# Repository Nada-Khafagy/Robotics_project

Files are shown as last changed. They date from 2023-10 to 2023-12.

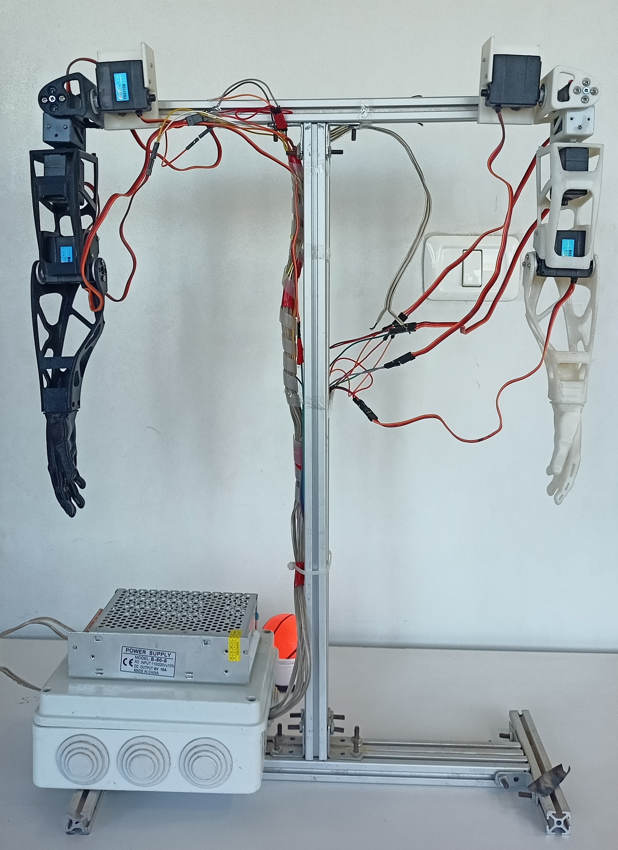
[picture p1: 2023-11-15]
right_arm/pics/wires_and _circuitry.jpg

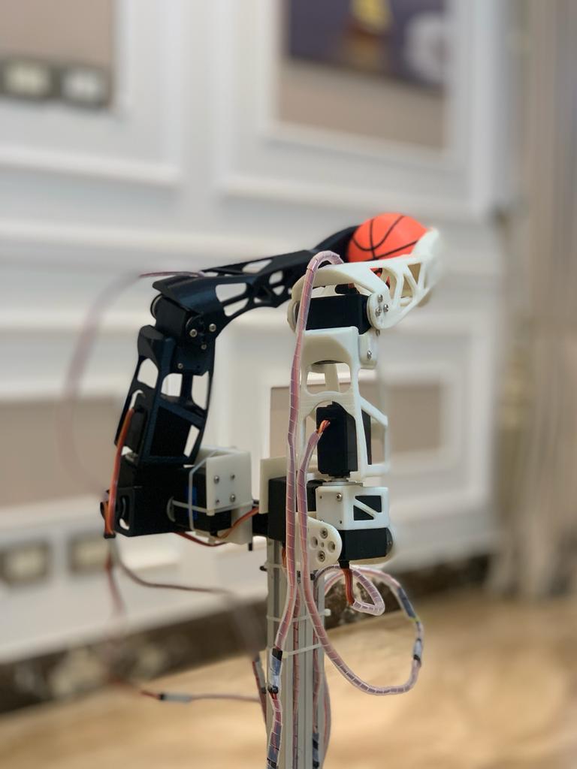
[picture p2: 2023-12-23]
RightLeftArms/fig/robot throwing the ball.jpg

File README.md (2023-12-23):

# Robotics_project

## Project Description

we will implement a robot that plays basketball :D 

# Basketball Project Team - slamDunk team
This is the official team page for the Basketball whole team. Meet our dedicated team members:

## Right Arm 
| Name | ID | GUC-mail | personal E-mail |
|---|---|---|---|
| Dina Mohamed | 49-18602 | dina.mohamed |dina67724@gmail.com |
| Marwa Lotfy | 49-18054 | marwa.hassan |lotfymarwa410@gmail.com  |
| Nada Tamer | 49-13614 | nada.abdelhay |nadatameer@outlook.com |
| Ahmed Mohamed Sleem |49-18230| ahmed.sleem |ahmedsleem.mail@gmail.com|
| Karim Emad Adam |49-17245 |karim.adam | |

## Left Arm 
| Name | ID | GUC-mail | personal E-mail |
|---|---|---|---|
| Shehab Ibrahim Mahmoud| 49-7639| shehab.abdallah | |
| Abdelfattah Gaber | 49-19487 | | |
| Ahmed Abdelhameed | 52-24471 | ahmed.elessawy | |
| Kareem Hindi | 49-3964  | Kareem.hindi |kareem.hindi12@gmail.com |
| Abdallah Amr | 49-10671 | | |

## To-Do List (Right hand)
- DONE :D

## To-Do List (Left hand)

## Project Timeline

- ~~registration --> 3/10~~
- ~~Milestone 1 --> 11/10~~
- ~~Milestone 2 --> 25/10~~
- ~~Milestone 3 --> 15/11~~
- ~~Milestone 4 --> 29/11~~
- ~~Milestone 5 --> 21/12~~
- DONE!!!!!!!!!!!!

## Video of working hardware
Robotic arm throwing a basket ball

## Contact Information
If you need to get in touch with our team, please feel free to reach out to us via the uni emails listed above by adding @student.guc.edu.eg or using personal mail.

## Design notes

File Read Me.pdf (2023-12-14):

To simulate the right arm only:

Open Matlab and simulink for the right arm >> Run humanoid_arm_DataFile >> Run HumanoidArmSyatem Simulink file

To simulate the both arms only:

Open Right and Left Simulink model >> Run Upper_Humanoid_DataFile >> Run Upper_Humanoid Simulink file

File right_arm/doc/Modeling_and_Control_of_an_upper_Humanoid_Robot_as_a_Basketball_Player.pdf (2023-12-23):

## Modeling and Control of an upper Humanoid Robot as a Basketball Player

Dina Mohamed∗

, Marwa Lotfy∗
,
Nada Tamer∗

, Ahmed Mohamed Sleem∗

and Karim Emad Adam∗
∗German University in Cairo (GUC), Egypt Emails: dina.mohamed@student.guc.edu.eg, marwa.hassan@student.guc.edu.eg, nada.abdelhay@student.guc.edu.eg, ahmed.sleem@student.guc.edu.eg, karim.adam@student.guc.edu.eg

Abstract—This project aims to design a system that can pick up and shoot a basketball with two robotic arms. It also focuses on creating interactive experiences for elderly individuals and children by engaging in playful activities with a softball. The project combines robotics, control systems, and entertainment to enhance well-being, social interaction, and physical activity for different age groups. Success will be measured by the system’s ability to accurately pick up and shoot the basketball.

Keywords-Robotics, Basketball, Control Systems.

I. INTRODUCTION

The integration of robotics and sports has marked a groundbreaking advancement in the field of technology, offering us the opportunity to explore new dimensions of human-machine interaction. In this context, our research delves into the fascinating realm of humanoid robotics, aiming to develop a Poppy humanoid arm system capable of playing basketball. This innovative project merges the intricacies of mechanical design, control, and robotics, presenting a significant step forward in the pursuit of enhancing both robotic capabilities and human-robot cooperation in dynamic and demanding environments.
The primary objective of this paper is to detail the design, modeling, and control strategies employed in the creation of a Poppy upper humanoid arm specifically optimized for playing basketball. The project seeks to bridge the gap between theoretical robotic design and real-world application in sports, with the ultimate goal of demonstrating how advanced robotics can be integrated into recreational activities, education, or even therapy for individuals with physical disabilities.
In section II, the robot’s hardware design and implementation is going to be presented.In section III techniques for forward kinematics are used, and techniques for Inverse kinematics are used in section IV. The section V presents the simulation results.

II. HARDWARE DESIGN AND IMPLEMENTATION

In order to build the hardware of the system, certain components are required as well, in addition, the connections circuit between the different components is shown.

A. Hardware Components
The poppy upper humanoid open source is used and 3D printed for hardware testing. For the motors, three double axes motors holding 10 kg.cm torque max and one motor holding 15 kg.cm for the shoulder to hold the whole system are used. ESP32 Microcontroller is used to control the four motors.

Table I: Hardware Components Table

Name of component | Location of purchasing | No. of items | Price
3D printed arm | Make It Real | 1 | 500
Servo motor 10kg.cm | Future electronics | 3 | 550
Servo motor 15kg.cm | Future electronics | 1 | 750
ESP32 | Ram electronics | 1 | 320
Power Supply | Ram electronics | 1 | 650
Wires, Jumpers | Future electronics | Some | 50
3d printed arm | Make It Real | 1 | 320
Aluminum Extrusion | CNC Egypt | 2 m | 160
L shape corner | CNC Egypt | 10 | 200
3d connecting part | Abdelhameed 3D printing | 1 | 50
Total | | | 3640
B. Circuit Diagram
As shown in Figure 1, the circuit consists of 4 motors, each having three connections, the voltage, the ground, and the signal which is the output of the micro controller. A breadboard is used to connect the wires at common nodes.

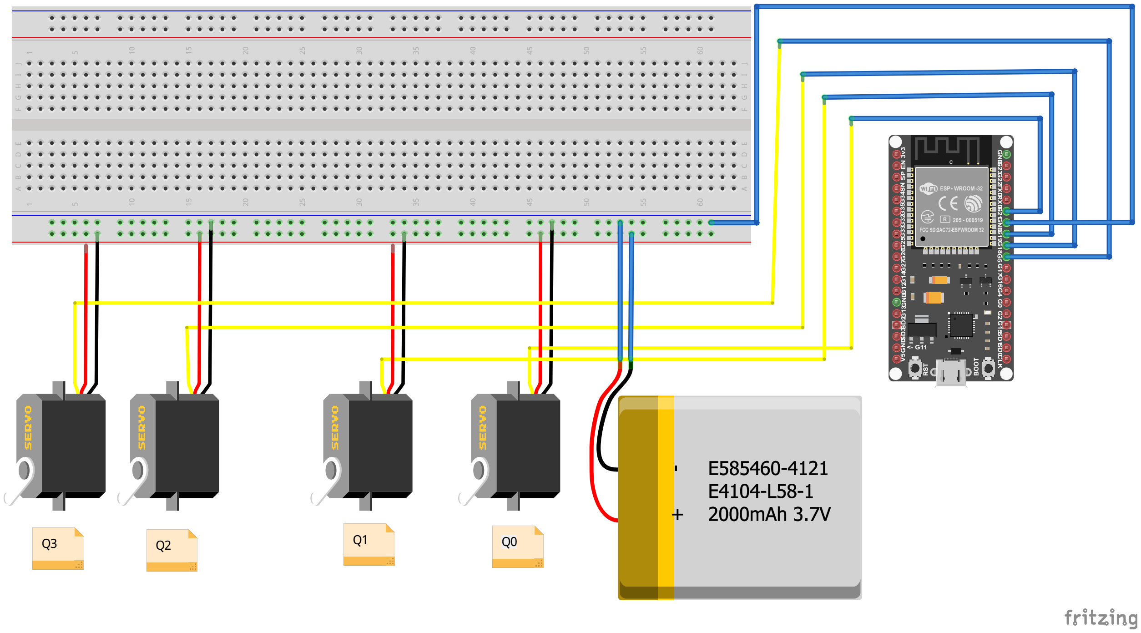
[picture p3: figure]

Figure 1: Circuit Diagram

III. FORWARD KINEMATICS

A. Denavit-Hartenberg (DH) convention

Forward kinematics using the Denavit-Hartenberg (DH) convention presented in [1] can be broken down into four key steps. First, assign DH axes to each joint of the robotic arm, ensuring they follow the right-hand rule as seen in Fig. 2. Second, fill out the DH parameters table, which includes values for the link lengths, joint angles, link twists, and offset distances, seen in II. This table is vital for the DH transformation process. Third, using these DH parameters, calculate the DH transformation matrices for each joint. These matrices represent the transformation between consecutive joints and are the building blocks for the final step. Lastly, obtain the end effector’s transformation matrix by multiplying the individual DH transformation matrices in a cascading manner. This final matrix describes the position and orientation of the robot’s end effector in the reference frame of the base, providing valuable information for controlling and planning the robot’s motion.

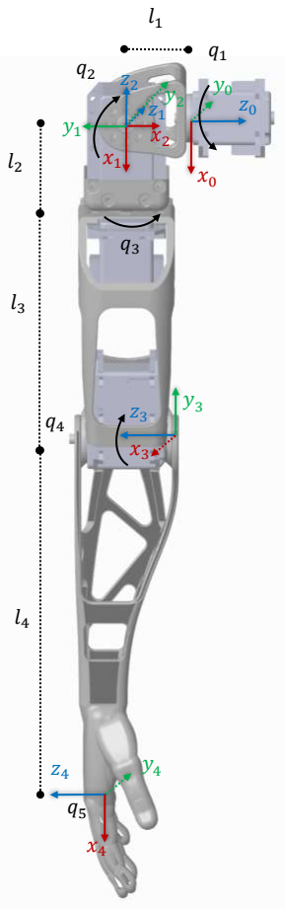
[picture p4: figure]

Figure 2: DH Frames.

joint(i) | θi | di | ai | αi
1 | q1 | −L1 | 0 | − π 2
2 | q2 − π 2 | 0 | 0 | π 2
3 | q3 − π 2 | −(L2 + L3) | 0 | π 2
4 | q4 − π 2 | 0 | L4 | 0

Table II: DH - Parameters table.

The distances between each joint is evaluated using a transform sensor and have the following values:

L1 | 0.02888114877491
L2 | 0.026599975
L3 | 0.122400025
L4 | 0.15

Table III: Lengths table.

IV. INVERSE KINEMATICS
Inverse kinematics refers to the process of determining the joint configurations of a robot’s manipulator that will result in a desired end-effector position and orientation. It involves finding the joint angles or joint displacements needed to achieve a specific pose (position and orientation) of the robot’s end-effector.
Let q represent the vector of joint variables, and p represent the desired end-effector position and orientation. The relationship between joint variables and end-effector pose is typically given by a kinematic function F(q):

F(q) = p

The goal of inverse kinematics is to solve for q given p. This is often a nonlinear problem due to the complex nature of robot kinematics.

A. Jacobian Matrix
The Jacobian matrix, denoted as J, relates the joint velocities q˙ to the end-effector linear and angular velocities v:

v = J(q) · q˙

Here, J(q) is the Jacobian matrix.

B. Newton-Raphson Method for Inverse Kinematics
The Newton-Raphson method is an iterative numerical technique used to find successively better approximations of the root of a real-valued function. In the context of inverse kinematics, it is applied to iteratively refine the joint variable estimates until the desired end-effector pose is achieved. The Newton-Raphson iteration for overactuated systems using the pseudo Jacobian can be expressed as:

qn+1 = qn + J

+(pdesired − F(qn))

Here,

- qn+1 is the updated estimate of joint variables.
- qn is the current estimate of joint variables.
- J

+ is the pseudo Jacobian matrix.
- pdesired is the desired end-effector pose.
- F(qn) is the current value of the kinematic function.

PSEUDO JACOBIAN FOR OVERACTUATED SYSTEM

In overactuated systems where we control more joints than the number of degrees of freedom of the end-effector (e.g., controlling x, y, z with 4 joints), the pseudo Jacobian J

+
can be used. For a 3-by-4 Jacobian J, the pseudo Jacobian is given by:

J

+ = J

T

(JJT
)

−1

This pseudo Jacobian allows the computation of joint velocities even in cases where the system is overactuated. The Newton-Raphson iteration for solving the inverse kinematics problem can then be modified with the pseudo Jacobian.
5
V. SIMULATIONS
A. Block diagram

The robot arm is exported from Solidworks, and then imported to Simscape and tested with different inputs, constants, sine waves, signal editor, and lastly, a slider. the following figures show the block diagram with the implemented forward and inverse Kinematics.

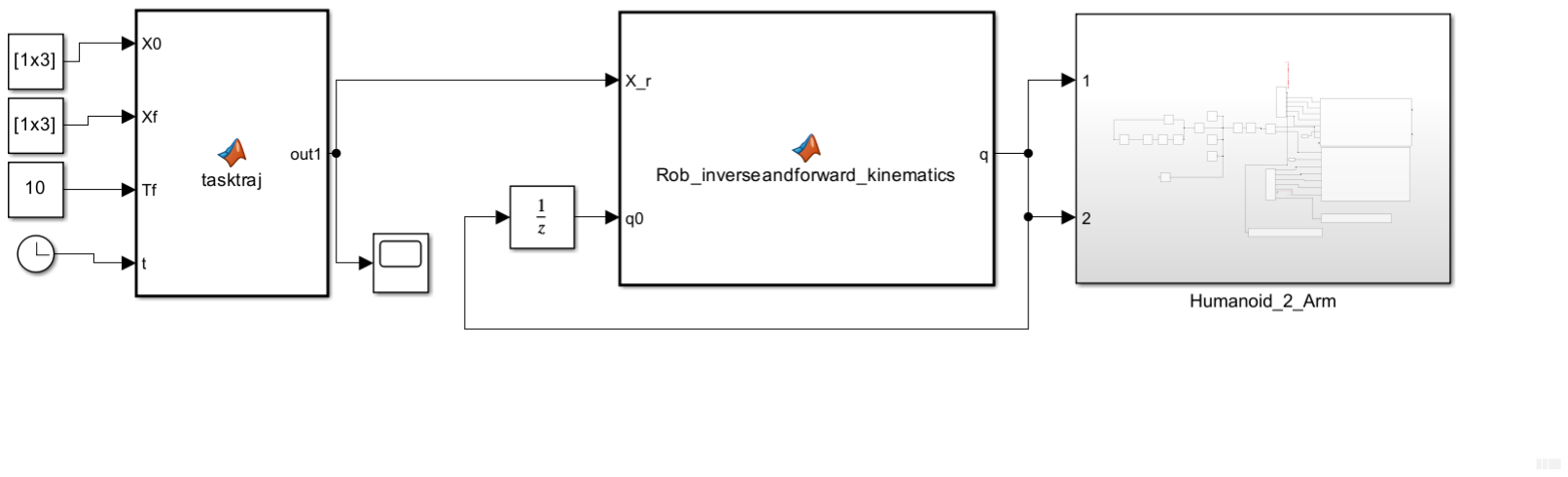
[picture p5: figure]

Figure 3: Block diagram part 1.

Ground and table are added to the simulation environment, in addition to a ball. Contact forces are added between the table and he ball and the robot hand and ball to in order for the robot to have contact with the ball as shown in fig4

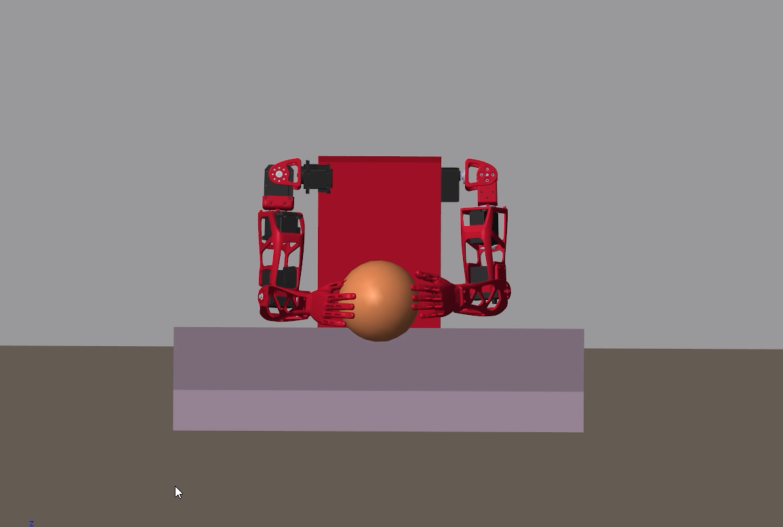
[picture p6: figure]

Figure 4: Both arms are connected in the Simulation

VI. TAJECTORY PLANNING

The robotic arm’s end effector will be first tested to follow a straight line according to the following data:
xi = [0.231, 0.07834, −0.05057]
xf = [0, 0.2, −0.05057]
Tf = 3
Ts = 0.1
qin = [40; 30; 20; 50]

where xi

is the initial position, xf is the final position, Tf is the duration (final time), Ts is the sampling time, and the qin is the initial angel The trajectory is shown in the following Figure:

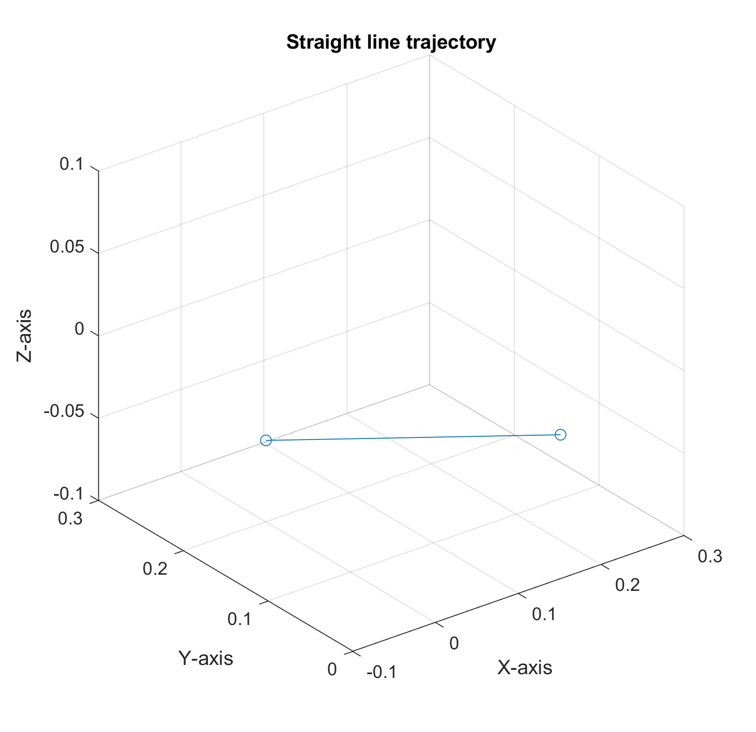
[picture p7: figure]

Figure 5: Straight line equation.

The produced angles will follow the trajectory in Fig.6, and the values for the Cartesian coordinates of the end effector will follow the values in Fig.7.

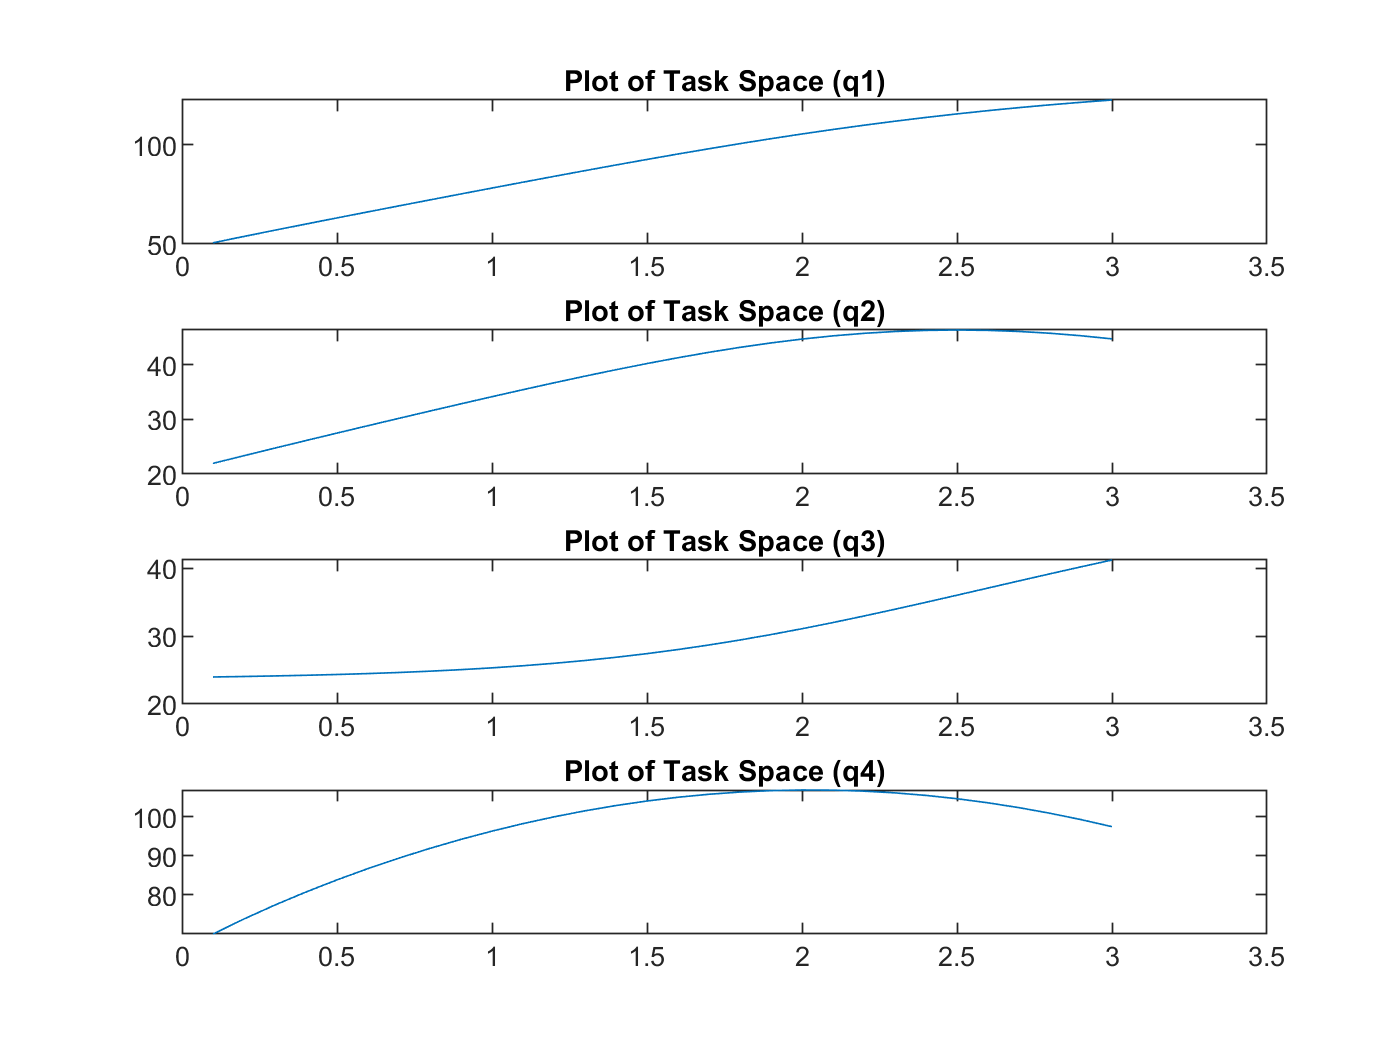
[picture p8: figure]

Figure 6: joint angles values at each time sample.

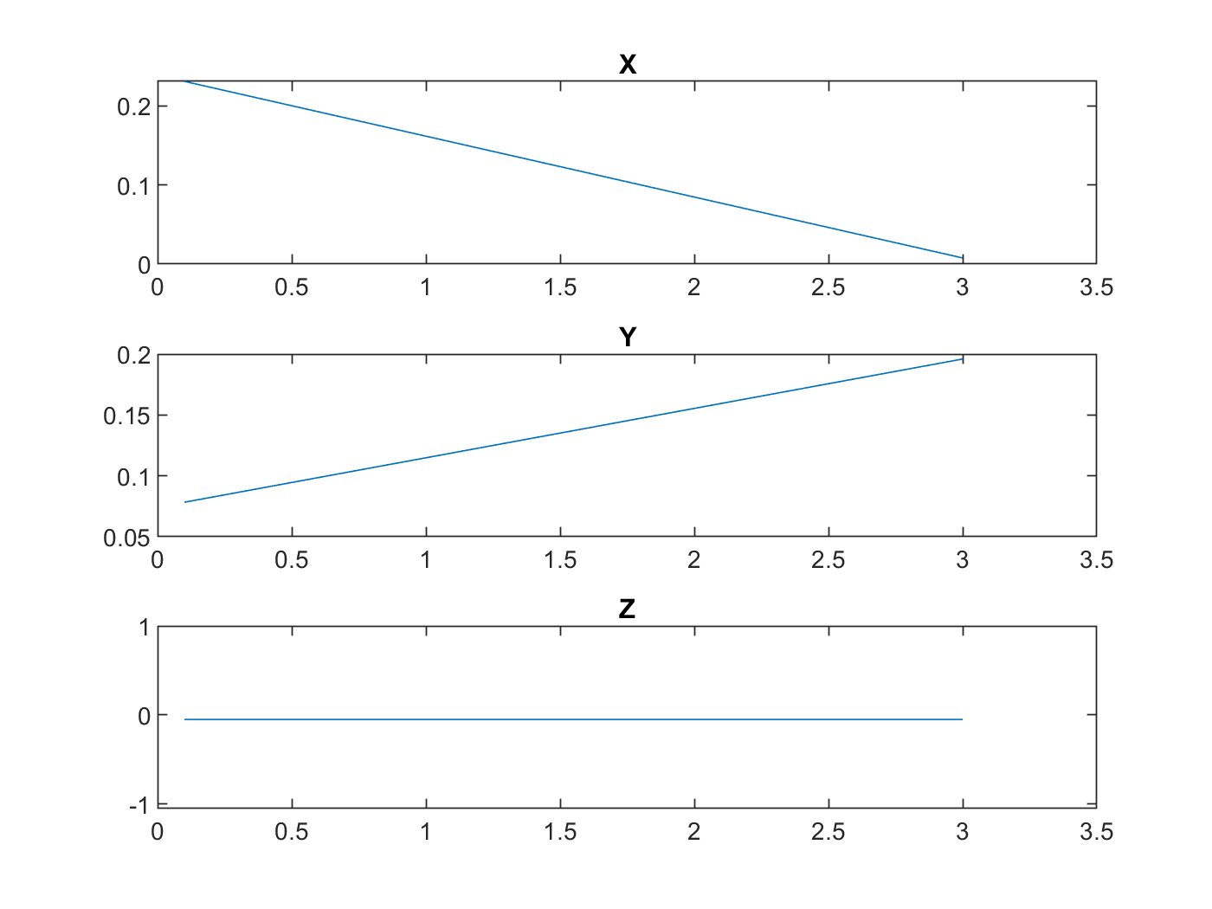
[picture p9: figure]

Figure 7: End effector path in space.

These values are tested in the simulink model as well, in order to verify that the angles will ensure that the trajectory of the end effector to be a straight line. After getting the values of the angles of each joint it was saved in an array and loaded in Arduino IDE to run on the fabricated hardware, the resulting trajectory is similar to the simulation with some tolerance, and shift that might be due to the shift in the zero position of the motor which can be solved by adding this shift to the given angle.

A. Implemented Final trajectory

For the Final Actual trajectory implementation, we combine both techniques, joint and task space trajectory planning, mainly joint space trajectory, using the first-degree polynomial equation of the following form:

q0 = c0 + c1t | (1)

Initially, the robot arm will be stationed at qinitial and then it will move to qfinal in ttotal seconds, so the coefficient values will be as follows:

c0 = qinitial | (2)

c1 =

(qfinal − qinitial)

ttotal

(3)

The overall trajectory consists of 5 trajectories, the first one is done using Task space trajectory planning as seen in Tab.IV, while the rest are done using Joint space trajectory planning, The joint angel list (q) contains the first, second, third and fourth joint values respectivly.

Traj. | initial value | final value
1 2 3 4 5 | x = 0.3, y = 0, z = −0.0288 q = [26°, −26°, −3, 49°, 49°] q = [59°, −28°, −12°, 84°] q = [26°, −26°, −3, 49°, 49°] q = [139°, 0°, −45°, 40°] | x : 0.148, y = −0.198, z = 0.075 q = [59°, −28°, −12°, 84°] q = [169°, −27°, −4°, 115°] q = [139°, 0°, −45°, 40°] q = [−1°, 0°, 0°, 0°]

Table IV: The 5 final trajectories.

The first trajectory (1) in Tab.IV moves the end effector (EE) towards the ball, while the second trajectory moves the (EE) upwards, the third trajectory moves it further up, the fourth trajectory throws the ball and the last fifth trajectory returns the robotic arms to the initial position.
The change in joint angles over time and their corresponding (EE) position are shown in Fig.8 and Fig.9.

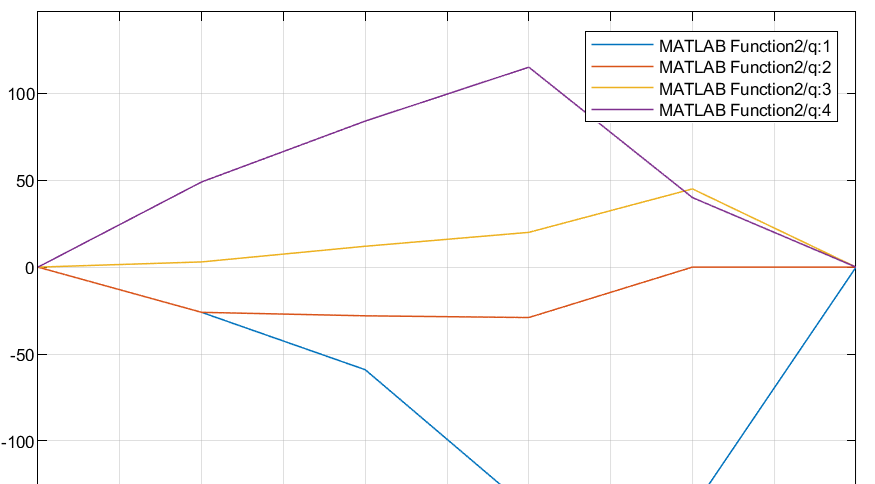
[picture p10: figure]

Figure 8: Change in joint angles over time in the final trajectory.

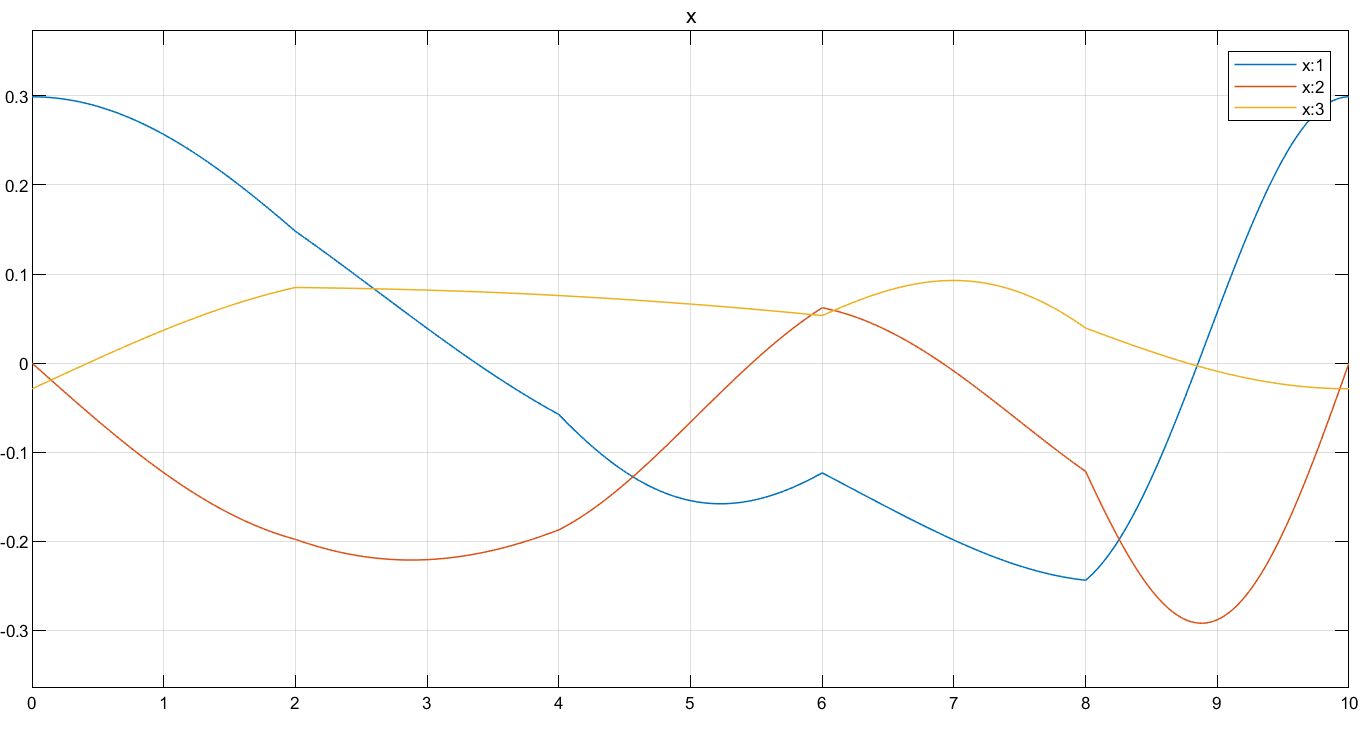
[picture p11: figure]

Figure 9: Change in (EE) position over time in the final trajectory.

VII. FINAL IMPLEMENTATION

The arm will be mounted on an aluminum extrusion fixation that is fixed together using L-shaped corners, in addition to another 3d printed part to fix the top motor with the aluminum extrusion, the arm is seen in the Fig. 10.

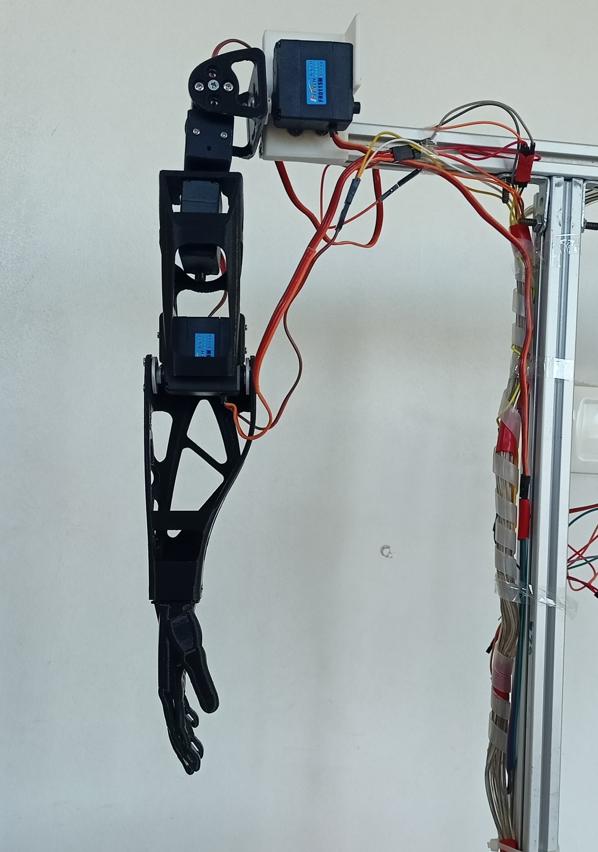
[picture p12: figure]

Figure 10: Fixed Right arm.

Finally, the other arm and the circuitry will be mounted as well, in order to achieve the objective of the robotic arm, which is playing basketball, as seen in Fig. 11.

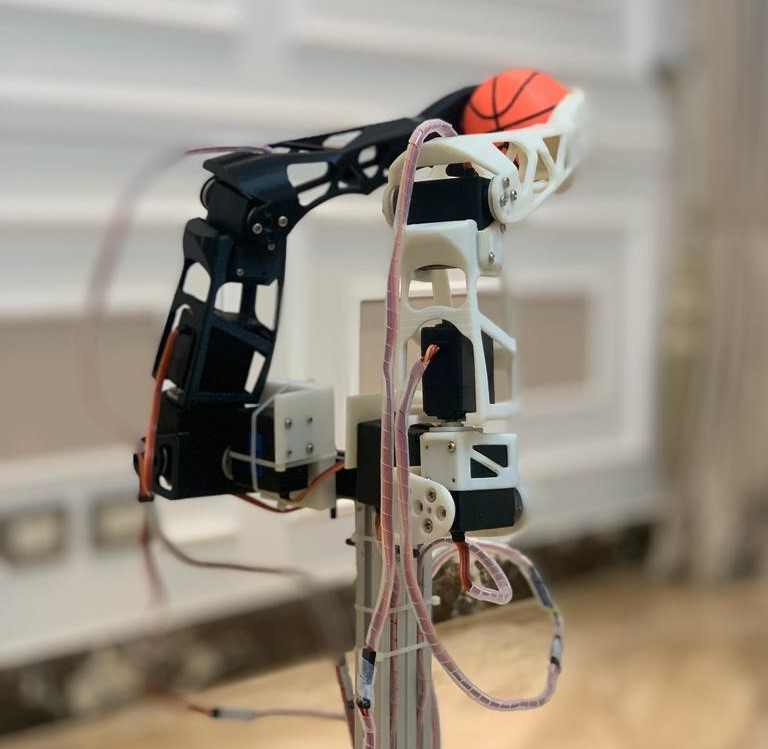
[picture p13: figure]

Figure 11: Both arms connected.

VIII. CONCLUSION

The arm movement on the actual hardware is consistent with the simulation results, The arm can pick up ball and throw it. Furthermore, other trajectories can be implemented on the robotic arm, while taking into consideration its limitation in space.
While, in this work only position control is implemented, for future works, force control can be implemented, as well as, precise position control of the landing ball, although it will lead to more challenges.

It is also believed that using higher degrees will lead to smoother movement of the robotic arm than the current results
In order to see the robotic arm in action, the following QR code can be scanned.

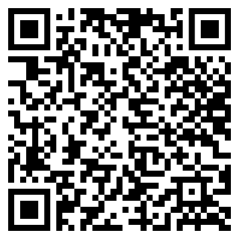
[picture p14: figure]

IX. APPENDIX
The Jacobian matrix J is given by:
j1 | j2 | j3 | j4
j5 | j6 | J7 | j8
j9 j10 j11 j12

Where

j1 =

π sin(q4)(cos(q1) cos(q3) − sin(q1) sin(q2) sin(q3))
| | 1200

−

149π cos(q2) sin(q1)
180000

−

π cos(q2) cos(q4) sin(q1)
1200

j2 = −

π cos(q1)(149 sin(q2) + 150 cos(q4) sin(q2) − 150 cos(q2) sin(q3) sin(q4)) 180000

j3 = −

π sin(q4)(sin(q1) sin(q3) − cos(q1) cos(q3) sin(q2))
1200
j4 = π cos(q4)(cos(q3) sin(q1) + cos(q1) sin(q2) sin(q3))
| | 1200

−

π cos(q1) cos(q2) sin(q4)
1200

j5 =

π sin(q4)(cos(q3) sin(q1) + cos(q1) sin(q2) sin(q3)) 1200

+

149π cos(q1) cos(q2)
180000

+

π cos(q1) cos(q2) cos(q4)
1200

j6 = −

π sin(q1)(149 sin(q2) + 150 cos(q4) sin(q2) − 150 cos(q2) sin(q3) sin(q4)) 180000

j7 =

π sin(q4)(cos(q1) sin(q3) + cos(q3) sin(q1) sin(q2))
1200

j8 = −

π cos(q4)(cos(q1) cos(q3) − sin(q1) sin(q2) sin(q3)) 1200

−

π cos(q2) sin(q1) sin(q4)
1200

j9 = 0

j10 = −

π cos(q2)(149π)
180000

−

π cos(q2) cos(q4)
1200

−

π sin(q2) sin(q3) sin(q4)
1200

j11 =

π cos(q2) cos(q3) sin(q4)
1200

j12 =

π sin(q2) sin(q4)
1200

+

π cos(q2) cos(q4) sin(q3)
1200

REFERENCES

[1] M. Spong, S. Hutchinson, and M. Vidyasagar, Robot Modeling and Control, ser. Wiley select coursepack. Wiley. [Online]. Available: https://books.google.com.eg/books?id=muCMAAAACAAJ (https://books.google.com.eg/books?id=muCMAAAACAAJ)

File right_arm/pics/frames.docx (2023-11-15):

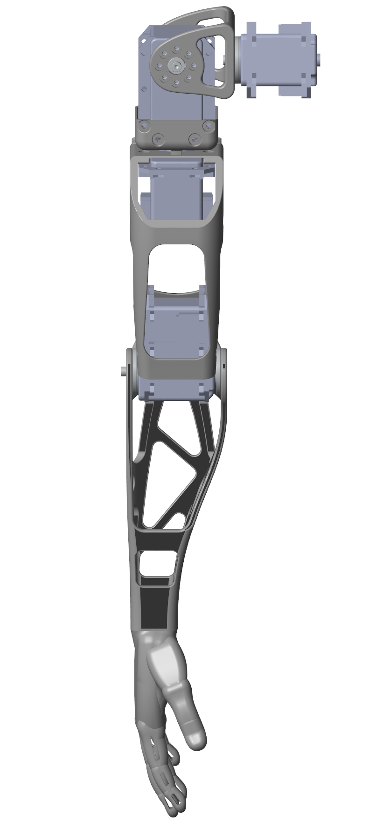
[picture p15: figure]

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
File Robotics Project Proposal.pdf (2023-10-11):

# Robotics Project Proposal

The goal of this robotics project is to design a robotic system with dual objectives: firstly, to pick up a basketball from a chosen position on the table using two robotic arms and successfully launch it into a nearby basket. Secondly, to create an engaging and interactive experience for both elderly individuals and children by utilizing these robotic arms to pick up a soft, lightweight ball and engage in playful activities, such as passing the ball with the users.

The project represents a combination of robotics, control systems, and entertainment, aiming to bring joy :D, social interaction, and physical activity to the lives of elderly residents in care facilities while also serving as a source of amusement and physical coordination practice for children. By combining these objectives, the project highlights the potential of robotics to enhance the well-being and happiness of different age groups through innovative and entertaining interactions, ultimately bridging the gap between advanced technology and meaningful human experiences.

The project's primary objectives include the design and implementation of the robotic arms, the development of control algorithms for precise manipulation, and trajectory planning. The robotic system's success will be measured by its ability to reliably pick up the basketball, accurately estimate the target basket's location, calculate an optimal throwing trajectory, and execute the throw with a high degree of accuracy and repeatability.

Key components of the project include:

Robotic Arm assembly: Two specialized robotic arms will be equipped with a combination of joints and motors that allow for delicate and precise manipulation of the basketball.

System Modeling and Analysis: The equations that describe the kinematics of our robot model will be derived and analyzed using Matlab. The projectile motion for the basketball motion is analyzed to obtain the equations of the projectile motion.

Trajectory Planning: A smooth trajectory will be designed in order to pick the ball in addition to another trajectory for throwing the ball with a certain firing angle and velocity.
Testing and Evaluation: Extensive testing and validation will be conducted to assess the system's performance, accuracy, and reliability under various conditions and scenarios. Adjustments and improvements will be made iteratively based on the results, the project will also be tested using Simulink and visualized using Simscape.

Right hand: Pick and launch the ball.
Left hand: Perform the same action as the right hand but mirrored.

## Sincerely, SlamDunk Team :)

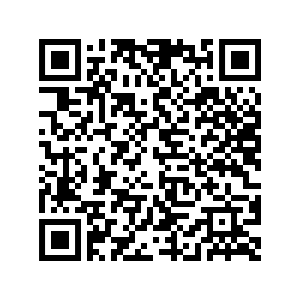
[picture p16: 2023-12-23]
RightLeftArms/media/robot_video_qr.png

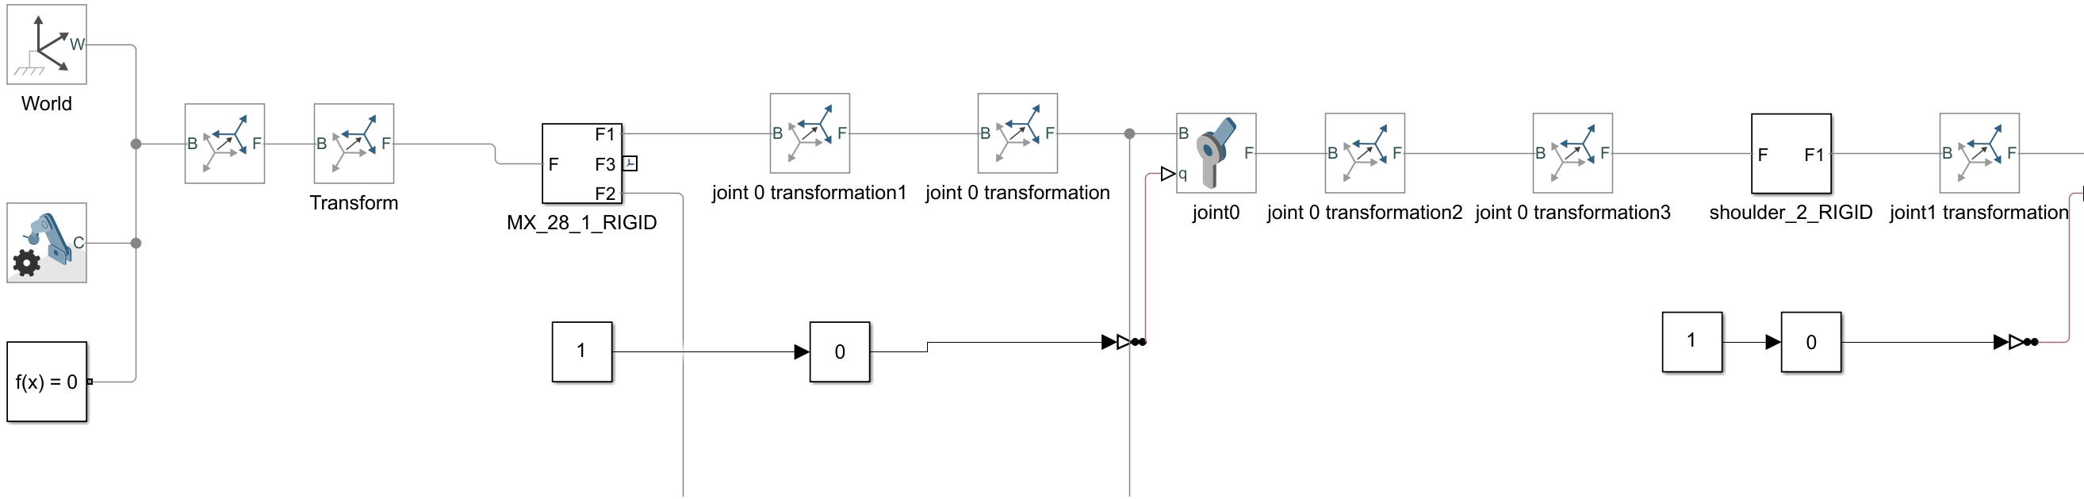
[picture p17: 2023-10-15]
right_arm/pics/blockDiagram_part1.png

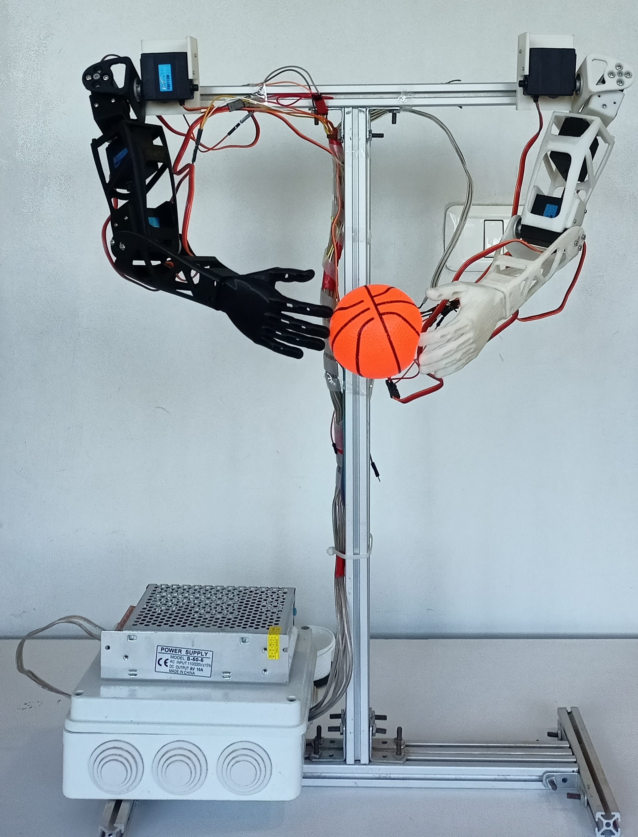
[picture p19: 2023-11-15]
right_arm/pics/Arm_with _basket.jpg

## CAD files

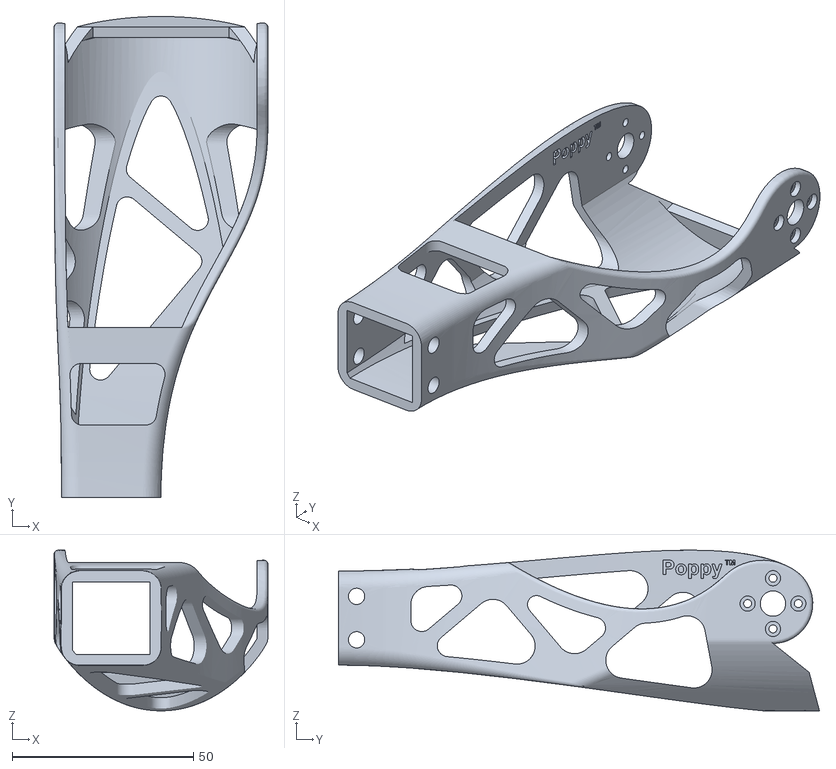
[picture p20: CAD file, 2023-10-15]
right_arm/hardware/Right Arm STL Files/forearm_R.STL
59.0 x 132.8 x 44.4

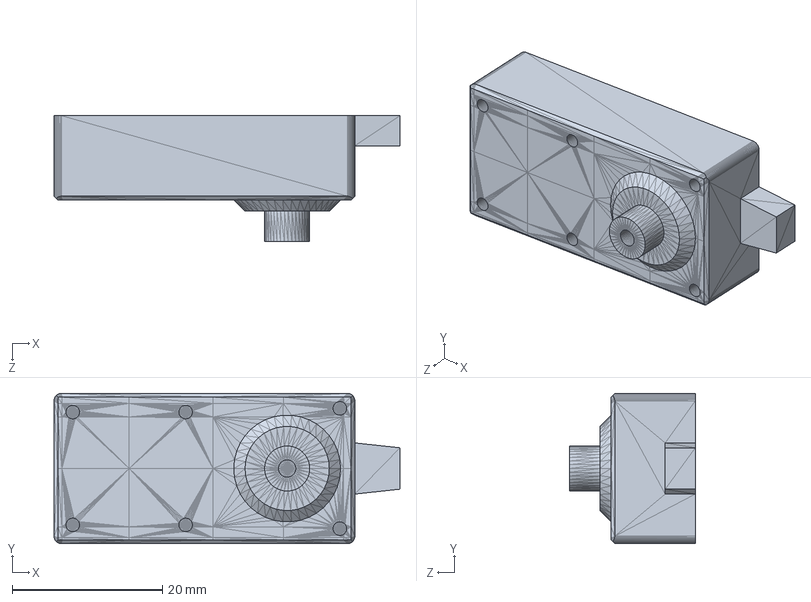
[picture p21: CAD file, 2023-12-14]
right_arm/Simscape_files/RDS3225 v7 motor - RDS3225 v7.step-1 RDS3225-1.step-1_Default_sldprt.STEP
46.0 x 20.0 x 16.7 mm

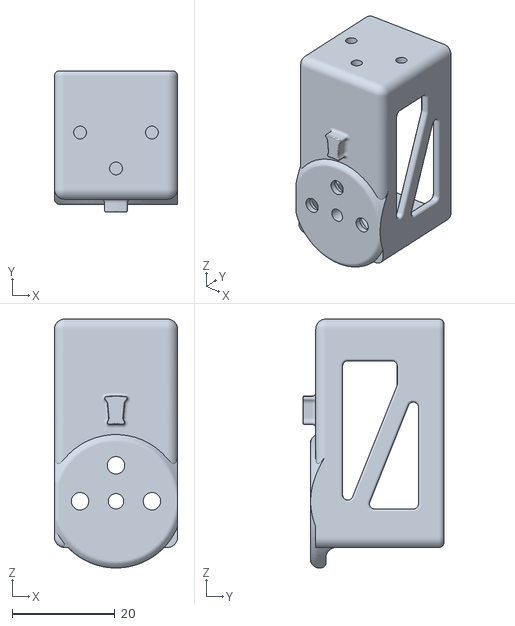
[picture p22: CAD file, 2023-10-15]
right_arm/hardware/Right Arm STL Files/arm_connector_LR.STL
24.0 x 27.5 x 48.5

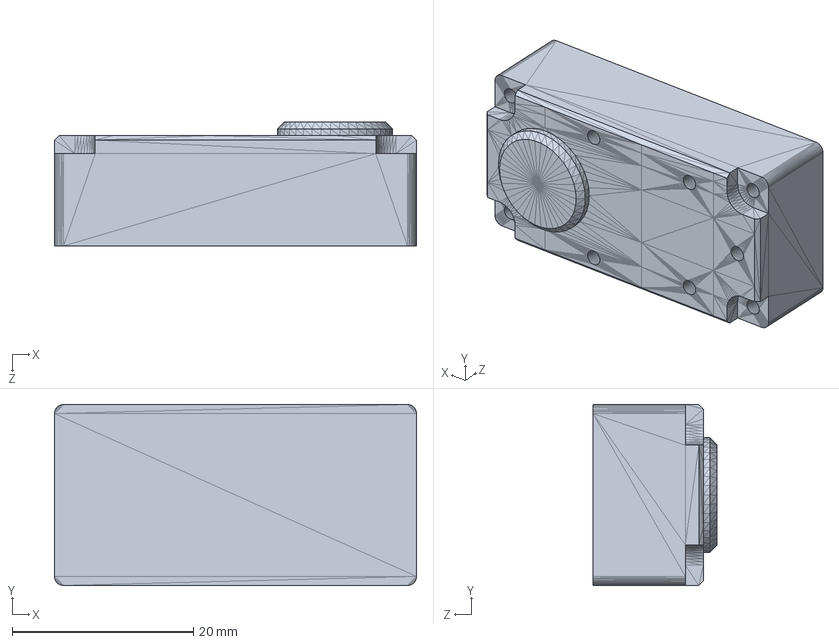
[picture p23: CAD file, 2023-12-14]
right_arm/Simscape_files/RDS3225 v7 motor - RDS3225 v7.step-1 RDS3225.step-1_Default_sldprt.STEP
40.0 x 20.0 x 13.7 mm

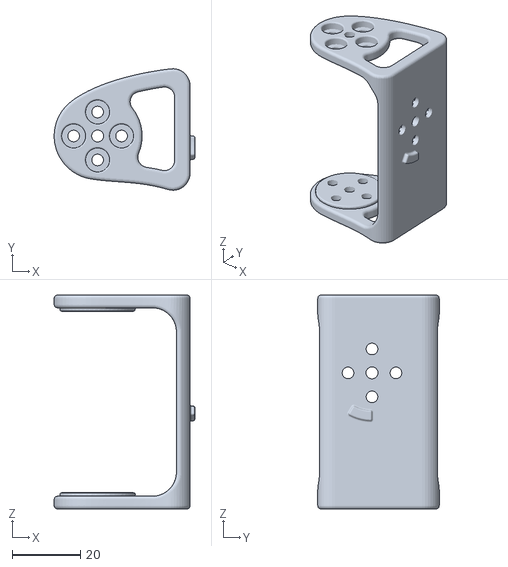
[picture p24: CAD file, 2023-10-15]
right_arm/hardware/Right Arm STL Files/Shoulder_R.STL
41.1 x 35.5 x 62.5

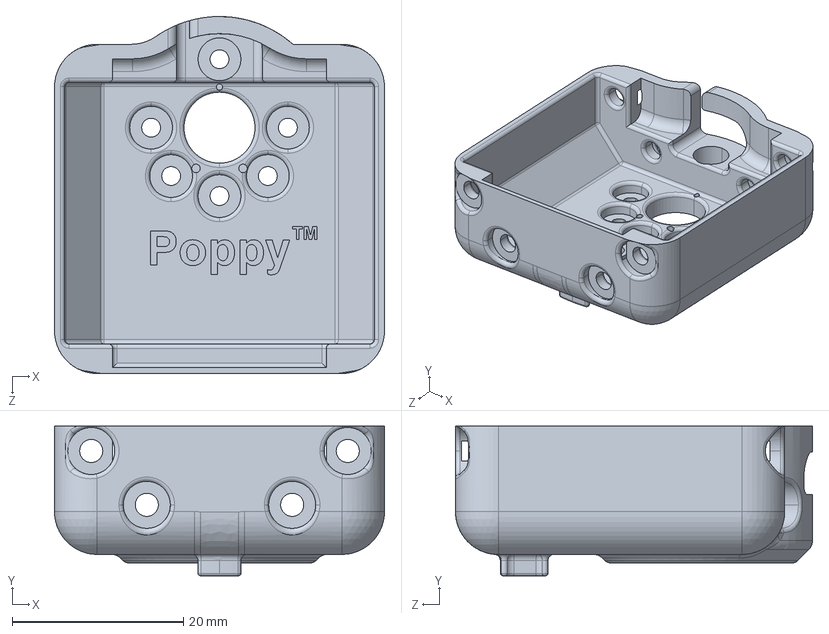
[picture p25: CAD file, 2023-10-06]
RightLeftArms/Simscape_files_updated/arm_connector_MX-28_sldprt.STEP
38.6 x 17.5 x 41.7 mm

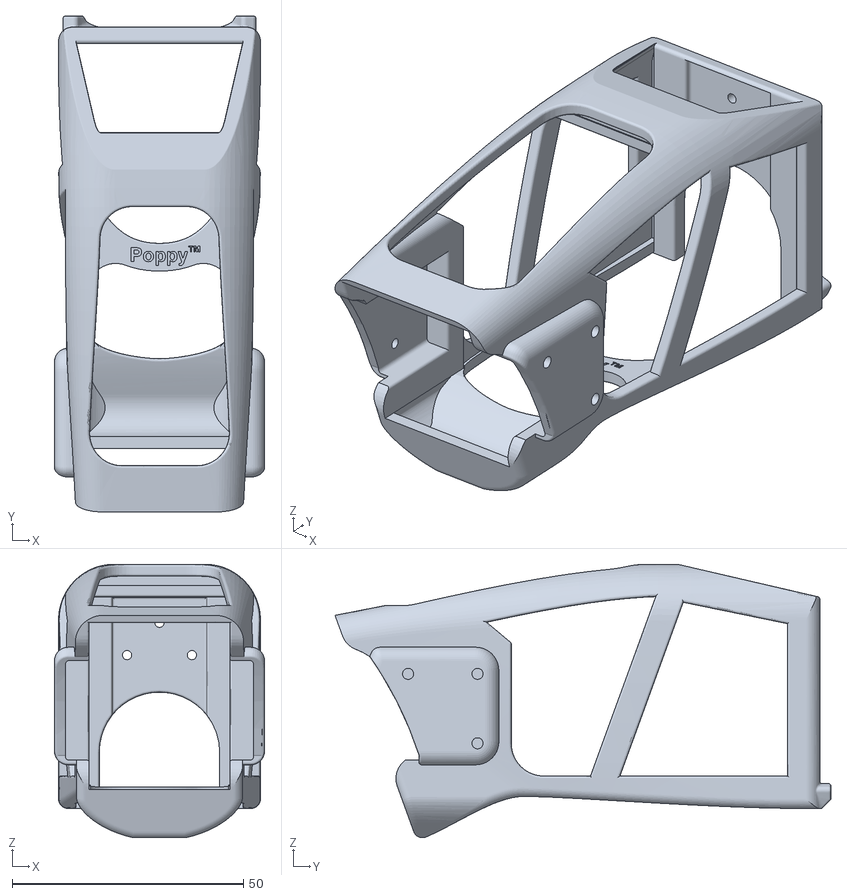
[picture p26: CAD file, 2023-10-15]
right_arm/hardware/Right Arm STL Files/upper_arm_LR.STL
45.4 x 107.1 x 59.1

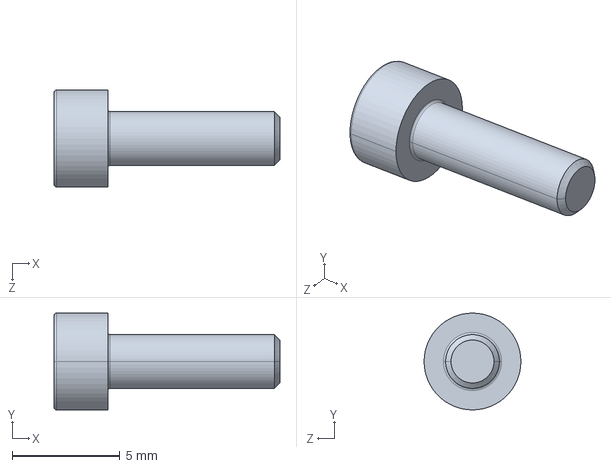
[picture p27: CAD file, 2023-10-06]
RightLeftArms/Simscape_files_updated/WB_M2.5x8_ISO 4762 M2.5 x 8 --- 8N_sldprt.STEP
10.5 x 4.50 x 4.50 mm

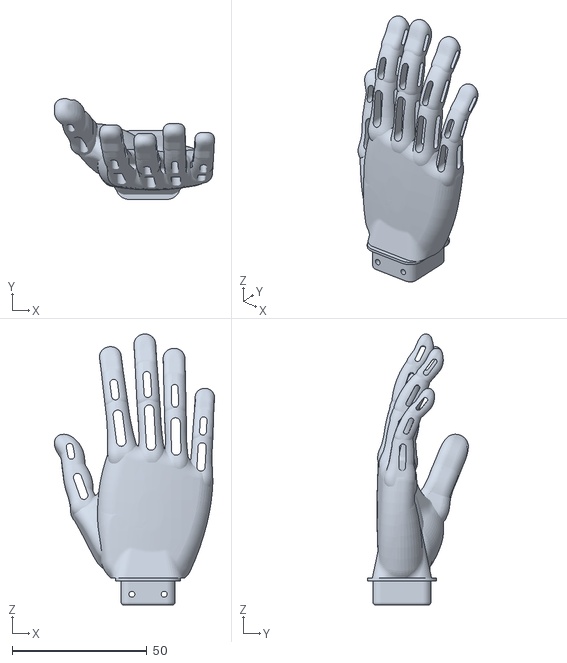
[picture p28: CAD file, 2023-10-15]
right_arm/hardware/Right Arm STL Files/hand_R.STL
59.4 x 37.4 x 100.6

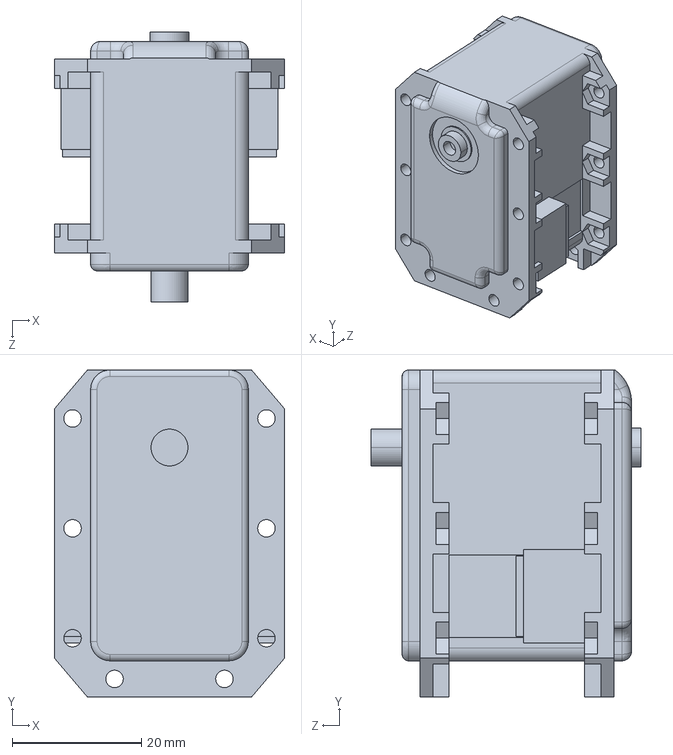
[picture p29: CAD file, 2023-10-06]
RightLeftArms/Simscape_files_updated/dynamixel_x28series_U_sldprt.STEP
35.6 x 50.6 x 41.9 mm

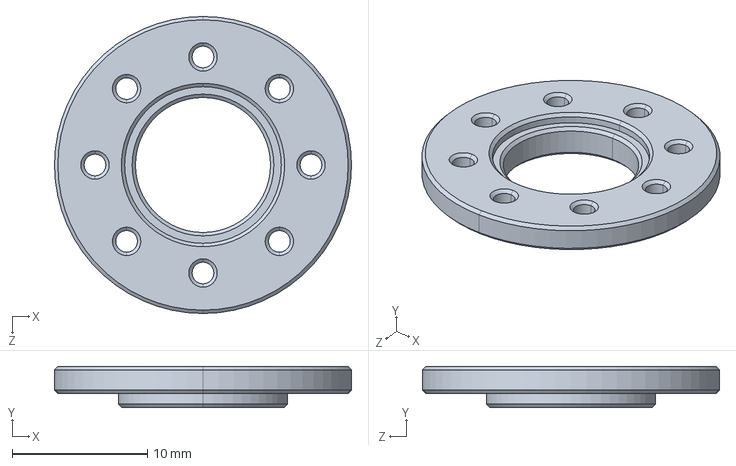
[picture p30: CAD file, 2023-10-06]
RightLeftArms/Simscape_files_updated/HN07-i101_Défaut_sldprt.STEP
22.0 x 3.05 x 22.0 mm

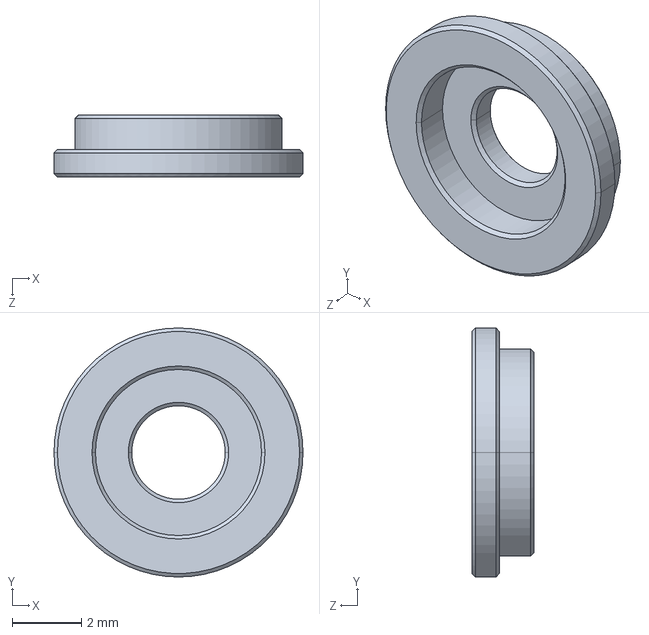
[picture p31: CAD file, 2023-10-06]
RightLeftArms/Simscape_files_updated/RX28-CAP_Défaut_sldprt.STEP
7.20 x 7.20 x 1.80 mm

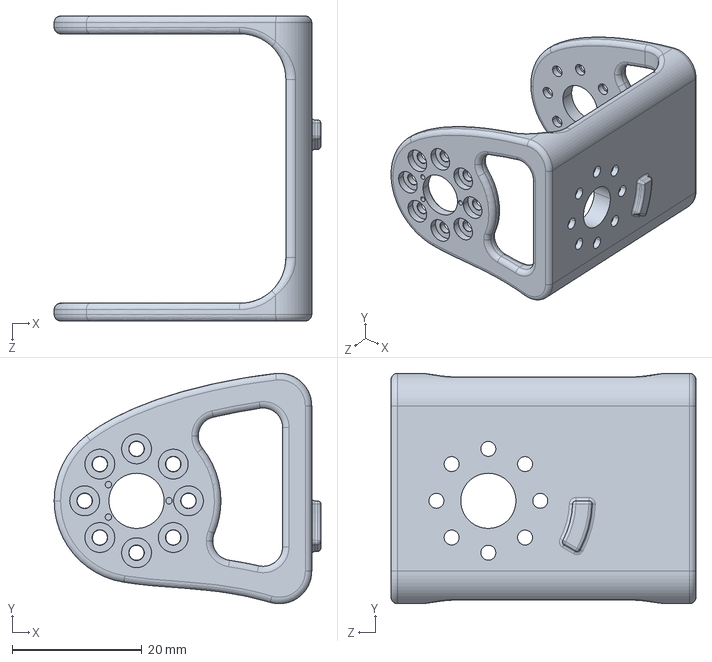
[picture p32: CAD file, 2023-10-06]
RightLeftArms/Simscape_files_updated/shoulder_MX-28_Right_sldprt.STEP
41.1 x 35.5 x 47.0 mm

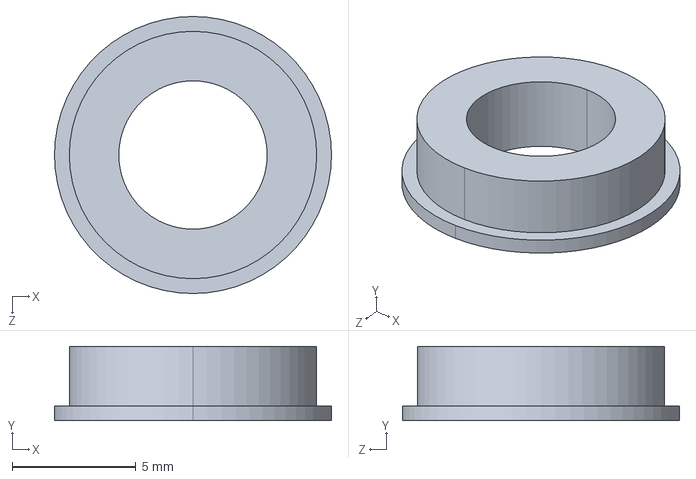
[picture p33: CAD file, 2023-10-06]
RightLeftArms/Simscape_files_updated/MF106ZZ_Défaut_sldprt.STEP
11.2 x 3.00 x 11.2 mm

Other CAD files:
RightLeftArms/Simscape_files_updated/dynamixel_x28series_Défaut_sldprt.STEP
RightLeftArms/Simscape_files_updated/forearm_MX-28-right_sldprt.STEP
RightLeftArms/Simscape_files_updated/HN07-N101_Défaut_sldprt.STEP
RightLeftArms/Simscape_files_updated/HN07-N101_U_sldprt.STEP
RightLeftArms/Simscape_files_updated/trust_washer_Défaut_sldprt.STEP
RightLeftArms/Simscape_files_updated/trust_washer_U_sldprt.STEP

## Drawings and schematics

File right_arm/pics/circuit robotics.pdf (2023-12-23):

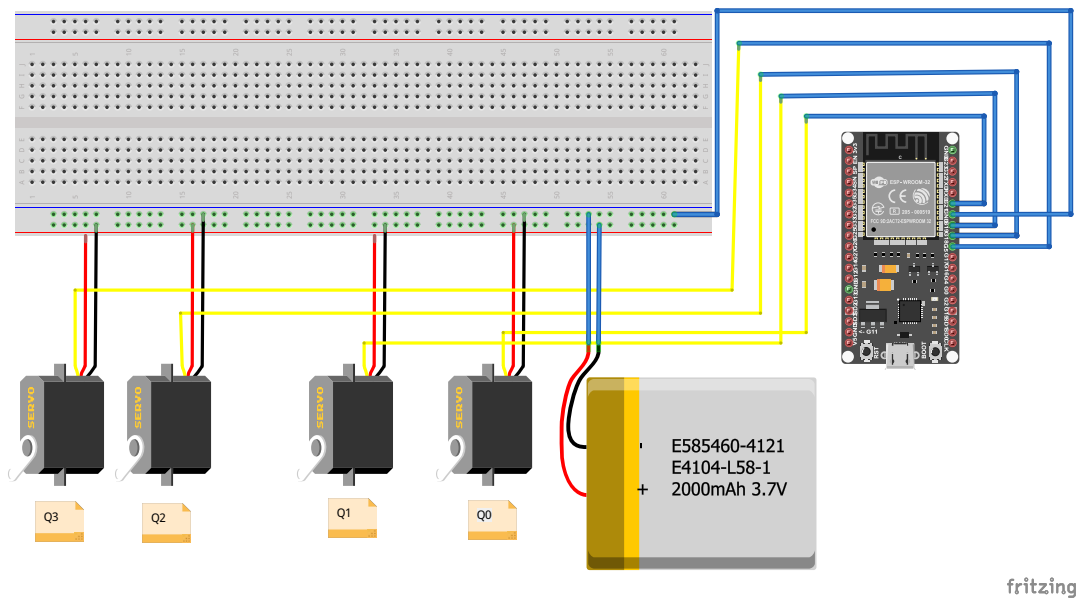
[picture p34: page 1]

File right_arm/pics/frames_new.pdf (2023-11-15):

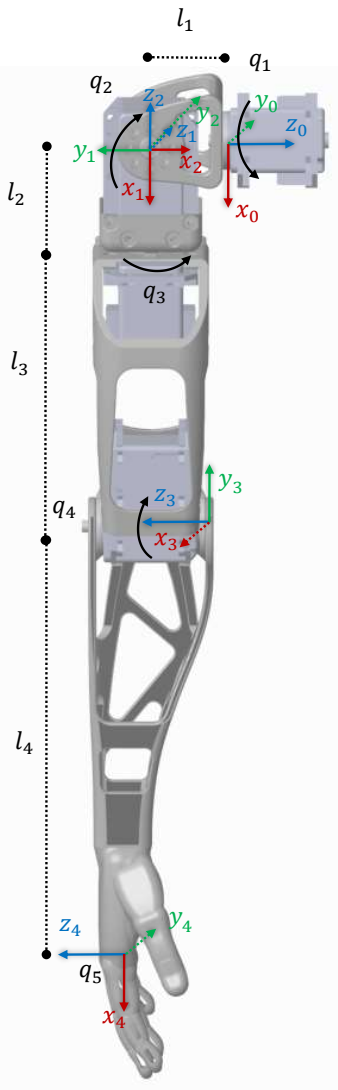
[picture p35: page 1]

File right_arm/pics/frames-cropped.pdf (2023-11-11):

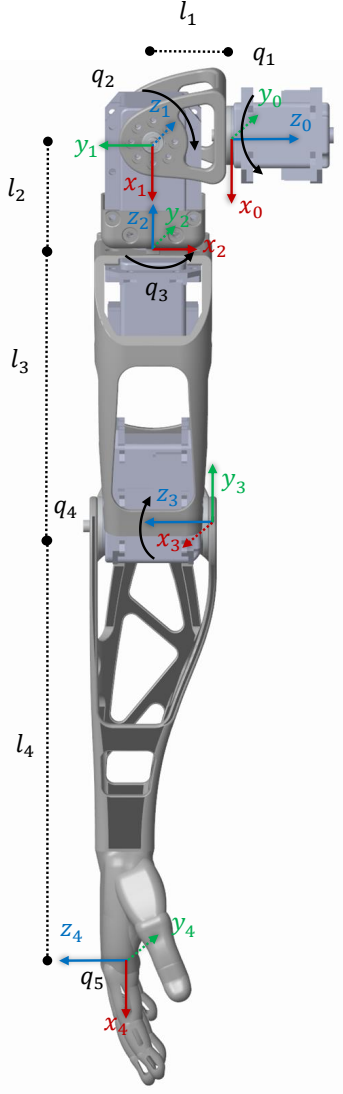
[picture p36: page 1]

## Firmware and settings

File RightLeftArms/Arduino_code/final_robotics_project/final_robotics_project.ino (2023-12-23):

#include <ESP32Servo.h>

#define Rmotor1 21
#define Rmotor2 19
#define Rmotor3 18
#define Rmotor4 5

#define Lmotor1 26
#define Lmotor2 27
#define Lmotor3 14
#define Lmotor4 12

#define button1 34
#define button2 35
#define button3 32
#define button4 33

  Servo myservo1;  
  Servo myservo2;
  Servo myservo3;
  Servo myservo4;
  Servo myservo5;  
  Servo myservo6;
  Servo myservo7;
  Servo myservo8;

  float elapsedT, T, TPrev;
  int i = 0 ;
  int pos ;    


void setup() {
  Serial.begin(9600);

  myservo1.attach(Rmotor1);  
  myservo2.attach(Rmotor2);
  myservo3.attach(Rmotor3);
  myservo4.attach(Rmotor4);

  myservo5.attach(Lmotor1);  
  myservo6.attach(Lmotor2);
  myservo7.attach(Lmotor3);
  myservo8.attach(Lmotor4);

  pinMode(button1,INPUT);
  pinMode(button2,INPUT);
  pinMode(button3,INPUT);
  pinMode(button4,INPUT);

   T = millis();
  }
  int f = 0 ;
void loop() {
  
  if(digitalRead(button1)==1){
    while(f<5){
   T = millis();
   elapsedT = (T - TPrev)/1000;
     if(elapsedT >= 0.015 && f==0){
     int servo1[]=  {1,1,2,2,3,3,3,4,4,4,5,5,5,6,6,6,7,7,7,8,8,8,9,9,9,10,10,10,11,11,11,11,12,12,12,13,13,13,14,14,14,15,15,15,16,16,16,16,17,17,17,18,18,18,19,19,19,20,20,20,21,21,21,22,22,22,23,23,23,24,24,24,25,25,26,26,26,27,27,27,27};
     int servo2[]=  {35,35,34,34,34,33,33,33,32,32,32,31,31,31,30,30,30,29,29,29,28,28,28,28,27,27,27,26,26,26,25,25,25,24,24,24,23,23,23,22,22,22,21,21,21,20,20,20,19,19,19,18,18,18,17,17,17,16,16,16,16,15,15,15,14,14,14,13,13,13,12,12,12,11,11,11,10,10,10,9,9};
     int servo3[] = {90,90,90,90,90,90,90,91,91,91,91,91,91,91,91,92,92,92,92,92,92,92,93,93,93,93,93,93,94,94,94,94,94,94,95,95,95,95,95,95,95,96,96,96,96,96,96,96,97,97,97,97,97,97,97,98,98,98,98,98,98,98,99,99,99,99,99,99,99,99,99,98,97,96.95,94,92,91,90,89,87};
     int servo4[] = {0,13,18,22,25,28,30,32,35,36,38,40,42,43,45,46,47,48,50,51,52,53,54,55,56,56,57,58,59,59,60,61,61,62,62,63,63,63,64,64,64,65,65,65,65,65,66,66,66,66,66,66,66,66,65,65,65,65,65,64,64,64,63,63,62,62,61,61,60,60,59,58,57,57,56,55,54,53,52,51,49};
      TPrev = T;
      myservo1.write(servo1[i]);
      myservo5.write(180-servo1[i]);
      myservo2.write(servo2[i]);
      myservo6.write(180-servo2[i]);
      myservo3.write(servo3[i]);
      myservo7.write(90-(servo3[i]-90));
      myservo4.write(servo4[i]);
      myservo8.write(servo4[i]);
      i++;
      if(i == 81){
      f = 1;
      i = 0;
      }
    }
      if(elapsedT >= 0.01 && f==1){
      TPrev = T;
      int servo5[] = {28,28,29,29,29,30,30,30,31,31,31,32,32,32,33,33,33,34,34,34,35,35,35,36,36,36,37,37,37,38,38,38,39,39,39,40,40,40,41,41,41,42,42,42,43,43,43,44,44,44,45,45,45,46,46,46,47,47,47,48,48,48,49,49,49,50,50,50,51,51,51,52,52,52,53,53,53,54,54,54,55,55,55,56,56,56,57,57,57,58,58,58,59,59,59,60};
      int servo6[] = {9,9,9,9,9,9,9,9,9,9,9,9,9,9,9,9,9,9,9,9,8,8,8,8,8,8,8,8,8,8,8,8,8,8,8,8,8,8,8,8,8,8,8,8,8,8,8,8,8,8,8,8,8,8,8,8,8,8,8,8,8,7,7,7,7,7,7,7,7,7,7,7,7,7,7,7,7,7,7,7,7};
      int servo7[] = {87,87,87,87,87,86,86,86,86,86,86,86,86,86,85,85,85,85,85,85,85,85,85,84,84,84,84,84,84,84,84,84,83,83,83,83,83,83,83,83,82,82,82,82,82,82,82,82,82,81,81,81,81,81,81,81,81,81,80,80,80,80,80,80,80,80,80,79,79,79,79,79,79,79,79,79,78,78,78,78,78};
      int servo8[] = {50,50,50,51,51,51,52,52,52,53,53,53,54,54,54,55,55,55,56,56,56,57,57,57,58,58,58,59,59,59,60,60,60,61,61,61,62,62,62,63,63,63,64,64,64,65,65,65,66,66,66,67,67,67,68,68,68,69,69,69,70,70,70,71,71,71,72,72,72,73,73,73,74,74,74,75,75,75,76,76,76,77,77,77,78,78,78,79,79,79,80,80,80,81,81,81,82,82,82,83,83,83,84};
      myservo5.write(180-servo5[i]);
      myservo1.write(servo5[i]);
      myservo6.write(180-servo6[i]);
      myservo2.write(servo6[i]);
      myservo7.write(90-(servo7[i]-90));
      myservo3.write(servo7[i]);
      myservo8.write(servo8[i]);
      myservo4.write(servo8[i]);
      i++;
      if(i == 81){
      f = 2;
      i = 0 ;
      }
    }
      if(elapsedT >= 0.01 && f==2){
       TPrev = T;
      int servo9 [] = {60,61,62,63,64,65,66,67,68,69,70,71,72,73,74,75,76,77,78,79,80,81,82,83,84,85,86,87,88,89,90,91,92,93,94,95,96,97,98,99,100,101,102,103,104,105,106,107,108,109,110,111,112,113,114,115,116,117,118,119,120,121,122,123,124,125,126,127,128,129,130,131,132,133,134,135,136,137,138,139,140};
      int servo10[] = {7,7,7,7,7,7,7,7,7,7,7,7,7,7,7,7,7,7,7,7,7,7,7,7,7,7,7,7,7,7,7,7,7,7,7,7,7,7,7,7,6,6,6,6,6,6,6,6,6,6,6,6,6,6,6,6,6,6,6,6,6,6,6,6,6,6,6,6,6,6,6,6,6,6,6,6,6,6,6,6,6};
      int servo11[] = {78,78,78,78,78,78,77,77,77,77,77,77,77,77,77,76,76,76,76,76,76,76,76,76,76,76,75,75,75,75,75,75,75,75,75,74,74,74,74,74,74,74,74,74,74,74,73,73,73,73,73,73,73,73,73,72,72,72,72,72,72,72,72,72,72,72,71,71,71,71,71,71,71,71,71,70,70,70,70,70,70};
      int servo12[] = {84,84,85,85,86,86,86,87,87,87,88,88,89,89,89,90,90,91,91,91,92,92,93,93,93,94,94,94,95,95,96,96,96,97,97,98,98,98,99,99,100,100,100,101,101,101,102,102,103,103,103,104,104,105,105,105,106,106,106,107,107,108,108,108,109,109,110,110,110,111,111,112,112,112,113,113,113,114,114,115,115};      
      myservo5.write(180-servo9[i]);
      myservo1.write(servo9[i]);
      myservo6.write(180-servo10[i]);
      myservo2.write(servo10[i]);
      myservo7.write(90-(servo11[i]-90));
      myservo3.write(servo11[i]);
      myservo8.write(servo12[i]);
      myservo4.write(servo12[i]);
      i++;
      if(i == 81){
      f = 3;
      i = 0 ;
      }
      }
       if(f==3){
       TPrev = T;
      delay(150);
      myservo2.write(35);
      myservo3.write(45);      
      myservo4.write(40);
      myservo6.write(180-35);
      myservo7.write(90-(45-90));
      myservo8.write(40);
      f = 4;
      i = 0 ;
      delay(150);
      Serial.println("ys");
      }
      if(elapsedT >= 0.02 && f==4){
       TPrev = T;
      int servo13 [] = {140,138,136,134,133,131,129,127,126,124,122,120,119,117,115,113,112,110,108,106,105,103,101,99,98,96,94,92,91,89,87,85,84,82,80,78,77,75,73,71,70,68,66,64,63,61,59,57,56,54,52,50,49,47,45,43,42,40,38,36,35,33,31,29,28,26,24,22,21,19,17,15,14,12,10,8,7,5,3,1,0};
      int servo14[] = {35,35,35,35,35,35,35,35,35,35,35,35,35,35,35,35,35,35,35,35,35,35,35,35,35,35,35,35,35,35,35,35,35,35,35,35,35,35,35,35,35,35,35,35,35,35,35,35,35,35,35,35,35,35,35,35,35,35,35,35,35,35,35,35,35,35,35,35,35,35,35,35,35,35,35,35,35,35,35,35,35};      
      int servo15[] = {45,45,46,46,47,47,48,48,49,50,50,51,51,52,52,53,54,54,55,55,56,56,57,57,58,59,59,60,60,61,61,62,63,63,64,64,65,65,66,66,67,68,68,69,69,70,70,71,72,72,73,73,74,74,75,75,76,77,77,78,78,79,79,80,81,81,82,82,83,83,84,84,85,86,86,87,87,88,88,89,90};
      int servo16[] = {40,39,39,38,38,37,37,36,36,35,35,34,34,33,33,32,32,31,31,30,30,29,29,28,28,27,27,26,26,25,25,24,24,23,23,22,22,21,21,20,20,19,19,18,18,17,17,16,16,15,15,14,14,13,13,12,12,11,11,10,10,9,9,8,8,7,7,6,6,5,5,4,4,3,3,2,2,1,1,0,0};      
      myservo5.write(180-servo13[i]);
      myservo1.write(servo13[i]);
      myservo6.write(180-servo14[i]);
      myservo2.write(servo14[i]);
      myservo7.write(90-(servo15[i]-90));
      myservo3.write(servo15[i]);
      myservo8.write(servo16[i]);
      myservo4.write(servo16[i]);
      i++;
      if(i == 81){
      f = 5;
      i = 0 ;
      }
      }
      Serial.println("no");
    }
    delay(150);
  }
f = 0 ;
i = 0 ;
  if(digitalRead(button2)==1){
     while(f<3){
    T = millis();
    elapsedT = (T - TPrev)/1000;
     if(elapsedT >= 0.02 && f==0){
     int servo16[]=  {0,1,2,3,4,5,6,7,9,10,11,12,13,14,15,16,18,19,20,21,22,23,24,25,27,28,29,30,31,32,33,34,36,37,38,39,40,41,42,43,45,46,47,48,49,50,51,52,54,55,56,57,58,59,60,61,63,64,65,66,67,68,69,70,72,73,74,75,76,77,78,79,81,82,83,84,85,86,87,88,90};
     int servo17[]=  {35,36,37,38,39,40,41,42,44,45,46,47,48,49,50,51,53,54,55,56,57,58,59,60,62,63,64,65,66,67,68,69,71,72,73,74,75,76,77,78,80,81,82,83,84,85,86,87,89,90,91,92,93,94,95,96,98,99,100,101,102,103,104,105,107,108,109,110,111,112,113,114,116,117,118,119,120,121,122,123,125};
     int servo18[] = {90,88,87,86,85,84,83,82,81,79,78,77,76,75,74,73,72,70,69,68,67,66,65,64,63,61,60,59,58,57,56,55,54,52,51,50,49,48,47,46,45,43,42,41,40,39,38,37,36,34,33,32,31,30,29,28,27,25,24,23,22,21,20,19,18,16,15,14,13,12,11,10,9,7,6,5,4,3,2,1,0};
     int servo19[] = {145,143,142,141,140,139,138,137,136,134,133,132,131,130,129,128,127,125,124,123,122,121,120,119,118,116,115,114,113,112,111,110,109,107,106,105,104,103,102,101,100,98,97,96,95,94,93,92,91,89,88,87,86,85,84,83,82,80,79,78,77,76,75,74,73,71,70,69,68,67,66,65,64,62,61,60,59,58,57,56,55};
     int servo20[] = {0,1,2,3,4,5,6,7,9,10,11,12,13,14,15,16,18,19,20,21,22,23,24,25,27,28,29,30,31,32,33,34,36,37,38,39,40,41,42,43,45,46,47,48,49,50,51,52,54,55,56,57,58,59,60,61,63,64,65,66,67,68,69,70,72,73,74,75,76,77,78,79,81,82,83,84,85,86,87,88,90};
      TPrev = T;
      myservo1.write(servo16[i]);
      myservo2.write(servo17[i]);      
      myservo3.write(servo18[i]);
      myservo4.write(0);
      myservo5.write(180);
      myservo6.write(servo19[i]);      
      myservo7.write(90);      
      myservo8.write(servo20[i]);
      i++;
      if(i == 81){
      f = 1;
      i = 0;
      }
      }
      if(elapsedT >= 0.02 && f==1){
     int servo21[]=  {125,123,122,120,119,117,116,114,113,111,110,108,107,105,104,102,101,99,98,96,95,93,92,90,89,87,86,84,83,81,80,78,77,75,74,72,71,69,68,66,65,63,62,60,59,57,56,54,53,51,50,48,47,45,44,42,41,39,38,36,35,33,32,30,29,27,26,24,23,21,20,18,17,15,14,12,11,9,8,6,5};
     int servo22[]=  {0,0,1,1,2,2,3,3,4,5,5,6,6,7,7,8,9,9,10,10,11,11,12,12,13,14,14,15,15,16,16,17,18,18,19,19,20,20,21,21,22,23,23,24,24,25,25,26,27,27,28,28,29,29,30,30,31,32,32,33,33,34,34,35,36,36,37,37,38,38,39,39,40,41,41,42,42,43,43,44,45};
     int servo23[] = {90,88,87,86,85,84,83,82,81,79,78,77,76,75,74,73,72,70,69,68,67,66,65,64,63,61,60,59,58,57,56,55,54,52,51,50,49,48,47,46,45,43,42,41,40,39,38,37,36,34,33,32,31,30,29,28,27,25,24,23,22,21,20,19,18,16,15,14,13,12,11,10,9,7,6,5,4,3,2,1,0};
      TPrev = T;
      myservo1.write(90);
      myservo2.write(servo21[i]);      
      myservo3.write(0);
      myservo4.write(servo22[i]);
      myservo5.write(180);
      myservo6.write(55);      
      myservo7.write(90);      
      myservo8.write(servo23[i]);
      i++;
      if(i == 81){
      f = 2;
      i = 0;
      }
      }
      if(elapsedT >= 0.02 && f==2){
     int servo24[]=  {90,88,87,86,85,84,83,82,81,79,78,77,76,75,74,73,72,70,69,68,67,66,65,64,63,61,60,59,58,57,56,55,54,52,51,50,49,48,47,46,45,43,42,41,40,39,38,37,36,34,33,32,31,30,29,28,27,25,24,23,22,21,20,19,18,16,15,14,13,12,11,10,9,7,6,5,4,3,2,1,0};
     int servo25[]=  {5,5,5,6,6,6,7,7,8,8,8,9,9,9,10,10,11,11,11,12,12,12,13,13,14,14,14,15,15,15,16,16,17,17,17,18,18,18,19,19,20,20,20,21,21,21,22,22,23,23,23,24,24,24,25,25,26,26,26,27,27,27,28,28,29,29,29,30,30,30,31,31,32,32,32,33,33,33,34,34,35};
     int servo26[] = {45,45,46,46,47,47,48,48,49,50,50,51,51,52,52,53,54,54,55,55,56,56,57,57,58,59,59,60,60,61,61,62,63,63,64,64,65,65,66,66,67,68,68,69,69,70,70,71,72,72,73,73,74,74,75,75,76,77,77,78,78,79,79,80,81,81,82,82,83,83,84,84,85,86,86,87,87,88,88,89,90};
     int servo27[] = {55,56,57,58,59,60,61,62,64,65,66,67,68,69,70,71,73,74,75,76,77,78,79,80,82,83,84,85,86,87,88,89,91,92,93,94,95,96,97,98,100,101,102,103,104,105,106,107,109,110,111,112,113,114,115,116,118,119,120,121,122,123,124,125,127,128,129,130,131,132,133,134,136,137,138,139,140,141,142,143,145};
      TPrev = T;
      myservo1.write(servo24[i]);
      myservo2.write(servo25[i]);      
      myservo3.write(servo26[i]);
      myservo4.write(0);
      myservo5.write(180);
      myservo6.write(servo27[i]);      
      myservo7.write(90);      
      myservo8.write(0);
      i++;
      if(i == 81){
      f = 3;
      i = 0;
      }
      }
     }
     delay(150);
  }
f = 0 ;
i = 0 ;
  if(digitalRead(button3)==1){
    while(f<2){
   T = millis();
   elapsedT = (T - TPrev)/1000;
     if(elapsedT >= 0.02 && f==0){
     int servo28[]=  {35,36,37,38,39,40,41,42,44,45,46,47,48,49,50,51,53,54,55,56,57,58,59,60,62,63,64,65,66,67,68,69,71,72,73,74,75,76,77,78,80,81,82,83,84,85,86,87,89,90,91,92,93,94,95,96,98,99,100,101,102,103,104,105,107,108,109,110,111,112,113,114,116,117,118,119,120,121,122,123,125};
      TPrev = T;
      myservo1.write(0);
      myservo2.write(servo28[i]);      
      myservo3.write(90);
      myservo4.write(0);
      myservo5.write(180);
      myservo6.write(180-servo28[i]);      
      myservo7.write(90);      
      myservo8.write(0);
      i++;
      if(i == 81){
      f = 1;
      i = 0;
      delay(5000);
      }
      }
      if(elapsedT >= 0.02 && f==1){
     int servo29[]=  {125,123,122,121,120,119,118,117,116,114,113,112,111,110,109,108,107,105,104,103,102,101,100,99,98,96,95,94,93,92,91,90,89,87,86,85,84,83,82,81,80,78,77,76,75,74,73,72,71,69,68,67,66,65,64,63,62,60,59,58,57,56,55,54,53,51,50,49,48,47,46,45,44,42,41,40,39,38,37,36,35};
      TPrev = T;
      myservo1.write(0);
      myservo2.write(servo29[i]);      
      myservo3.write(90);
      myservo4.write(0);
      myservo5.write(180);
      myservo6.write(180-servo29[i]);      
      myservo7.write(90);      
      myservo8.write(0);
      i++;
      if(i == 81){
      f = 2;
      i = 0;
      }
      }
      
    }
  }
f = 0 ;
i = 0 ;
  if(digitalRead(button4)==1){
   while(f<3){
   T = millis();
   elapsedT = (T - TPrev)/1000;
     if(elapsedT >= 0.02 && f==0){
     int servo30[]= {0,1,3,4,6,7,9,10,12,13,15,16,18,19,21,22,24,25,27,28,30,31,33,34,36,37,39,40,42,43,45,46,48,49,51,52,54,55,57,58,60,61,63,64,66,67,69,70,72,73,75,76,78,79,81,82,84,85,87,88,90,91,93,94,96,97,99,100,102,103,105,106,108,109,111,112,114,115,117,118,120};
     int servo31[]= {35,34,34,34,34,33,33,33,33,32,32,32,32,31,31,31,31,30,30,30,30,29,29,29,29,28,28,28,28,27,27,27,27,26,26,26,26,25,25,25,25,24,24,24,24,23,23,23,23,22,22,22,22,21,21,21,21,20,20,20,20,19,19,19,19,18,18,18,18,17,17,17,17,16,16,16,16,15,15,15,15};
     int servo32[]= {0,0,1,2,2,3,4,4,5,6,6,7,8,8,9,10,11,11,12,13,13,14,15,15,16,17,17,18,19,19,20,21,22,22,23,24,24,25,26,26,27,28,28,29,30,30,31,32,33,33,34,35,35,36,37,37,38,39,39,40,41,41,42,43,44,44,45,46,46,47,48,48,49,50,50,51,52,52,53,54,55};
      TPrev = T;
      myservo1.write(servo30[i]);
      myservo5.write(180-servo30[i]);
      myservo2.write(servo31[i]);
      myservo6.write(180-servo31[i]);
      myservo3.write(90);
      myservo7.write(90-(90-90));
      myservo4.write(servo32[i]);
      myservo8.write(servo32[i]);
      i++;
      if(i == 81){
      f = 1;
      i = 0;
      }
      }
      if(elapsedT >= 0.02 && f==1){
     int servo33[]= {120,118,117,115,114,112,111,109,108,106,105,103,102,100,99,97,96,94,93,91,90,88,87,85,84,82,81,79,78,76,75,73,72,70,69,67,66,64,63,61,60,58,57,55,54,52,51,49,48,46,45,43,42,40,39,37,36,34,33,31,30,28,27,25,24,22,21,19,18,16,15,13,12,10,9,7,6,4,3,1,0};
     int servo34[]= {15,15,16,17,18,19,20,21,22,23,24,25,26,27,28,29,30,30,31,32,33,34,35,36,37,38,39,40,41,42,43,44,45,45,46,47,48,49,50,51,52,53,54,55,56,57,58,59,60,60,61,62,63,64,65,66,67,68,69,70,71,72,73,74,75,75,76,77,78,79,80,81,82,83,84,85,86,87,88,89,90};
     int servo35[]= {55,54,53,52,52,51,50,50,49,48,48,47,46,46,45,44,44,43,42,41,41,40,39,39,38,37,37,36,35,35,34,33,33,32,31,30,30,29,28,28,27,26,26,25,24,24,23,22,22,21,20,19,19,18,17,17,16,15,15,14,13,13,12,11,11,10,9,8,8,7,6,6,5,4,4,3,2,2,1,0,0};
      TPrev = T;
      myservo1.write(servo33[i]);
      myservo5.write(180-servo33[i]);
      myservo2.write(servo34[i]);
      myservo6.write(180-servo34[i]);
      myservo3.write(90);
      myservo7.write(90-(90-90));
      myservo4.write(servo35[i]);
      myservo8.write(servo35[i]);
      i++;
      if(i == 81){
      f = 2;
      i = 0;
      delay(5000);
      }
      }
      if(elapsedT >= 0.02 && f==2){
      int servo36[]= {90,89,88,87,87,86,85,85,84,83,83,82,81,81,80,79,79,78,77,76,76,75,74,74,73,72,72,71,70,70,69,68,68,67,66,65,65,64,63,63,62,61,61,60,59,59,58,57,57,56,55,54,54,53,52,52,51,50,50,49,48,48,47,46,46,45,44,43,43,42,41,41,40,39,39,38,37,37,36,35,35};
      TPrev = T;
      myservo1.write(0);
      myservo5.write(180);
      myservo2.write(servo36[i]);
      myservo6.write(180-servo36[i]);
      myservo3.write(90);
      myservo7.write(90-(90-90));
      myservo4.write(0);
      myservo8.write(0);
      i++;
      if(i == 81){
      f = 3;
      i = 0;
      }
      }


   }
}
f = 0 ;
i = 0 ;

}

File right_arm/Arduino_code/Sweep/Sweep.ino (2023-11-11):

#include <Servo.h>

Servo motor1;
Servo motor2;
Servo motor3;
Servo motor4;
int pos = 0;
void setup() {

  motor1.attach(11);   // Attach motor1 to pin 9
  motor2.attach(9);  // Attach motor2 to pin 10
  
  motor3.attach(6);  // Attach motor4 to pin 12
  motor4.attach(10);  // Attach motor3 to pin 9
  Serial.begin(9600);
}

void loop() {
  for (pos = 0; pos <= 40; pos += 1) { // goes from 0 degrees to 180 degrees
    // in steps of 1 degree
    motor1.write(pos);              // tell servo to go to position in variable 'pos'
    delay(15);                       // waits 15 ms for the servo to reach the position
  }

  for (pos = 40; pos >= 0; pos -= 1) { // goes from 180 degrees to 0 degrees
    motor1.write(pos);              // tell servo to go to position in variable 'pos'
    delay(15);                       // waits 15 ms for the servo to reach the position
  }


  for (pos = 0; pos >= 40; pos += 1) { // goes from 180 degrees to 0 degrees
    motor2.write(pos);              // tell servo to go to position in variable 'pos'
    delay(15);                       // waits 15 ms for the servo to reach the position
  }


   for (pos = 40; pos <= 0; pos -= 1) { // goes from 0 degrees to 180 degrees
    // in steps of 1 degree
    motor2.write(pos);              // tell servo to go to position in variable 'pos'
    delay(15);                       // waits 15 ms for the servo to reach the position
  }



 for (pos = 0; pos <= 30; pos += 1) { // goes from 0 degrees to 180 degrees
    // in steps of 1 degree
    motor3.write(pos);              // tell servo to go to position in variable 'pos'
    delay(15);       
 }
  for (pos = 30; pos >= 0; pos -= 1) { // goes from 180 degrees to 0 degrees
    motor3.write(pos);              // tell servo to go to position in variable 'pos'
    delay(15);       
}

for (pos = 30; pos <=0; pos -= 1) { // goes from 0 degrees to 180 degrees
    // in steps of 1 degree
    motor4.write(pos);              // tell servo to go to position in variable 'pos'
    Serial.write(pos); //اتحرق؟
    delay(15);
          
 }
 
  delay(100);
}

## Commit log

2023-10-06 simscape test
    [HN07-N101_Défaut_sldprt.STEP, HN07-N101_U_sldprt.STEP, HN07-i101_Défaut_sldprt.STEP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]
2023-10-06 organize stuff
    [HN07-N101_Défaut_sldprt.STEP, HN07-N101_U_sldprt.STEP, HN07-i101_Défaut_sldprt.STEP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]
2023-10-10 add folder
    [HN07-N101_Défaut_sldprt.STEP, HN07-N101_U_sldprt.STEP, HN07-i101_Défaut_sldprt.STEP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]
2023-10-10 add folders
    [HN07-N101_Défaut_sldprt.STEP, HN07-N101_U_sldprt.STEP, HN07-i101_Défaut_sldprt.STEP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]
2023-10-11 add frames
2023-10-11 fix frames
2023-10-11 add docs
    [circuit robotics.fzz]
2023-10-11 Motor Frame Translation
2023-11-12 Forward Kinematics function on simulink
2023-11-12 Inverse Kinematics and forward kinematics on simulink
2023-11-14 Inverse Kinematics
2023-11-14 inverse jacobian and inverse position kinematics on matlab
2023-11-14 jacobian derivative, forward velocity kinematics, forward accel kinematics
2023-11-14 velocity inv kinematics and accel inv kinematics
2023-11-30 Two arms are imported in one file
    [HN07-N101_Défaut_sldprt.STEP, HN07-N101_U_sldprt.STEP, HN07-i101_Défaut_sldprt.STEP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]
2023-11-30 arduino code
    [matrix_data.xlsx]
2023-11-30 edit arduino code
2023-12-22 Joint space simulation added
2023-12-23 Last Milestone
    [circuit robotics.fzz]
